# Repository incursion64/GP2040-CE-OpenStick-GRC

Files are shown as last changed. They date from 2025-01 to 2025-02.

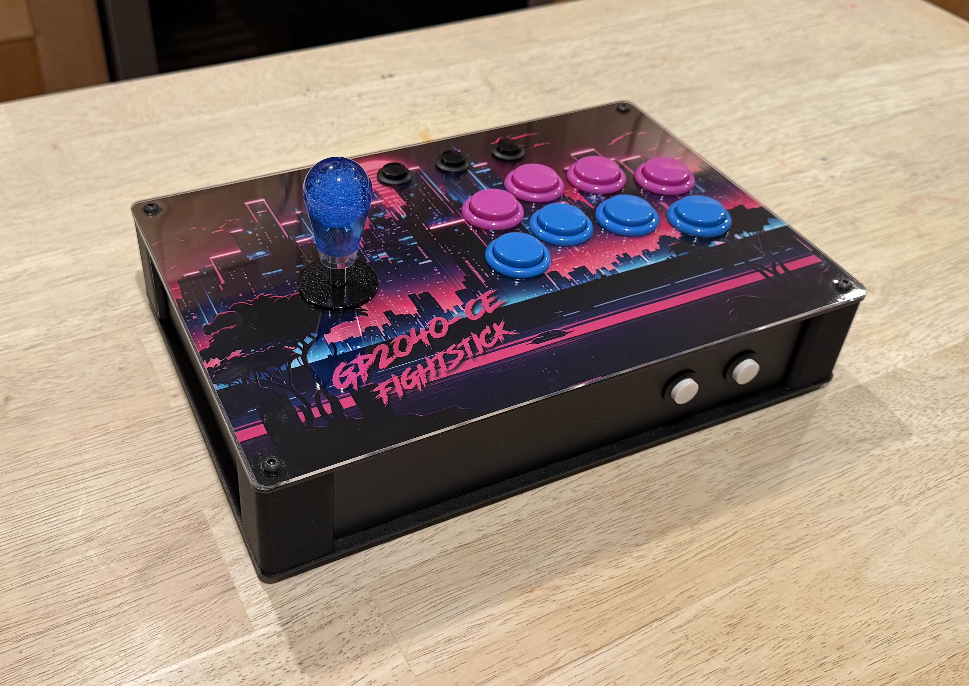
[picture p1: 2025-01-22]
z_readme assets/IMG_3226.jpg

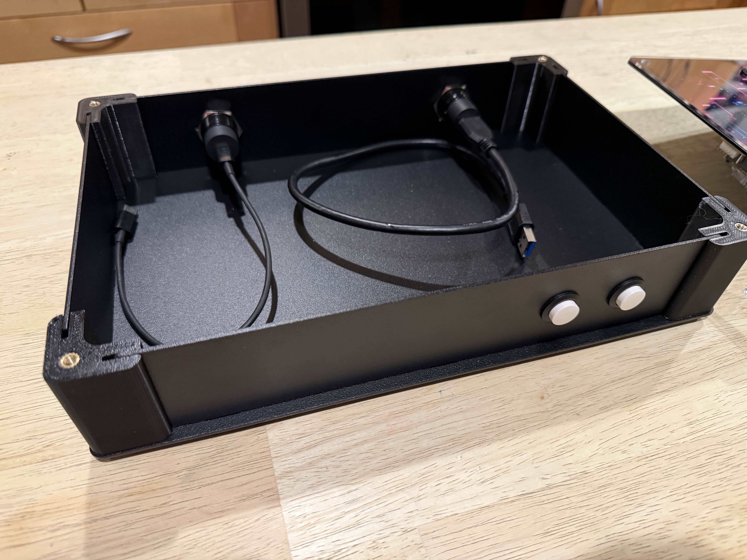
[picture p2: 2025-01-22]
z_readme assets/IMG_3221.jpg

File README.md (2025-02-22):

# GP2040-CE OpenStick by Game Room Customs (gameroomcustoms.com) 
 Custom Arcade Fight Stick

 The goal here was to design something heavyweight and durable but also offer something that was modular and easy to build and looks nice. 
 Steel Construction - 14GA CRS - Powder Coated
 3D Printed PETG Corners with threaded M4 Inserts
 3D Printed Custom Stick Spacer (to control height of the stick petruding from the case toper) This height is really based on preference. 
 Custom printed & machine cut graphics
 1.6mm Clear Acrylic Cover/graphic protector
 Rubber Non Slip feet







Included in this repository are all necessary files to process the material.
 - 2D DXF Files for laser cut metal & plastic cover
 - STL files for 3D printed Corners and spacer
 - PDF dimensionalized Prints
 - Bill of Materials for what i used

Graphic Template has not been included as you need only import the 2D DXF to Adobe illustrator or preferred program to process your artwork. 
If you decide to go with a snap in type button, be mindful that you can work with the approx 3-4mm thickness. I was able to get Sanwa genuine and clones in there. For the
clone types i had to make sure clips/anchors pushed out all the way so the button is secure. 1/16 or 1.6mm clear acrylic is recommended when usinf geniune sanwa buttons. 

Also note that i use a stick spacer.  This is not necessary if you want your stick to sit higher, but i added a 6mm (1/4") thick spacer to set the height where i like it. You could always add stick extensions as well. 

At a later date i will offer the build components or pre-built kits on my shop if anyone is interested.  
https://gameroomcustoms.com/

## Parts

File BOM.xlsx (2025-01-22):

BOM | Part | Description | Qty
1 | 100-100-101 - Corner Brackets | Black PETG - 3D Print | 4
2 | 100-100-102 - Stick Spacer | Black PETG - 3D Print | 1
3 | 100-100-103 - Top Plate | 14GA CRS - Laser Cut & Powder Coated Raven Black | 1
4 | 100-100-104 - Bottom Plate | 14GA CRS - Laser Cut & Powder Coated Raven Black | 1
5 | 100-100-105 - Side Plate | 14GA CRS - Laser Cut & Powder Coated Raven Black | 2
6 | 100-100-106 - Front Plate | 14GA CRS - Laser Cut & Powder Coated Raven Black | 1
7 | 100-100-107 - Back Plate Dual | 14GA CRS - Laser Cut & Powder Coated Raven Black | 1
8 | 100-100-108 - Black Plate Single | 14GA CRS - Laser Cut & Powder Coated Raven Black | 1 | optional in lieu of dual plate
9 | 100-100-109 - Acrylic Cover | 2mm Acrylic Cover - Laser Cut | 1 | 1mm may be prefeable depending on buttons/media (such as graphic)
10 | Litoexpe M4 Threaded Inserts | Brass Heat Set Insert Kit knurled Insert Nuts for Plastic 3D Printing | 8
11 | LifCratms Rubber Bumpers | Transparent Rubber Cutting Board Feet, Round Clear Rubber Bumpers Feet Pads Non-Slip Bumpers | 4
12 | Flat Head Cap Screws | iexcell M5 X 16mm Flat Head Cap Screws - Black Oxide | 4
13 | 18-8 Hex Nuts | 18-8 Stainless Steel Hex Nut, Black Oxide Finish, DIN 934, Metric, M5-0.8 Thread Size, 8 mm Width Across Flats, 4 mm Thick | 4
14 | M3 Flat Hed Machine Screws | M3 X 16mm PH Flat Head Screws - Black Oxide | 4
15 | M3 Hex Nuts | M3 Hex Nuts - Black Oxide | 4
16 | M3 Nylon Spacers | 3*3*7 MM Round Spacer Nylon - Black | 4
17 | USBC Port | AVSSZ Connectors USB 3.0 2.0 Type C Metal Data Adapter C / Round Computer Data Module, Single/Dual Interface Mounting Size 22mm | 1
18 | USBA Port | AVSSZ Connectors USB 3.0 2.0 Type A Metal Data Adapter A / Round Computer Data Module, Single/Dual Interface Mounting Size 22mm | 1
19 | GP2040-CE | Advanced Breakout Board V5.6E | 1
20 | 16mm Momentary Push Button | Multiple Color Available. Amazon has a multicolor pack | 6
21 | Sanwa - OBSF-30 | Snap in 30mm Arcade Buttons | 8
22 | Sanwa - JLF-TP-8YT | JLF-TP-8YT Joystick Black Original - for Arcade Jamma Game 4 & 8 Way Adjustable | 1
23 | Harness | Fighting Board Cable 20-Pin Quick Connect | 1 | Optional
24 | USB C to USB C Wire | Short 30cm Type C to USB C Cable Fast Charging For Iphone15 Xiaomi Samsung Huawei Power BanK 25cm USB To Type C/USB C Data Cable | 1
25 | USB A to USB A | USB Male to Male Cable USB A to USB Cord USB 3.0 Cable Double End USB Cord 5Gbps for Radiator Hard Disk USB 3.0 Extender Cable. .5m Long | 1

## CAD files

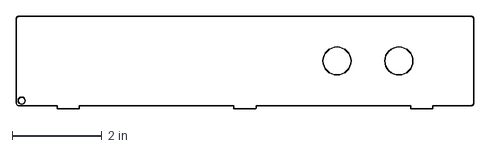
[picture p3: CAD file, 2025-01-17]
2D CAD Files/Front Plate_14GA CRS.dxf
10.2 x 2.07 in

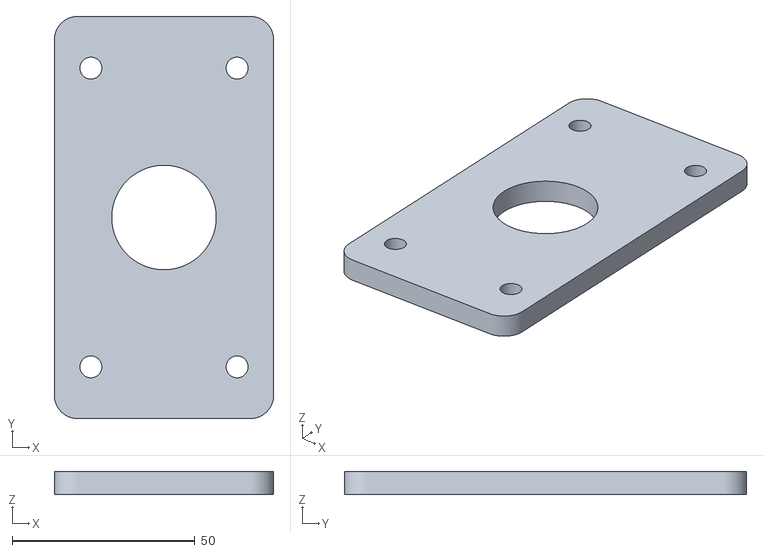
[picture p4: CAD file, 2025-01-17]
STL Files/Stick Spacer.stl
60.0 x 110.0 x 6.35

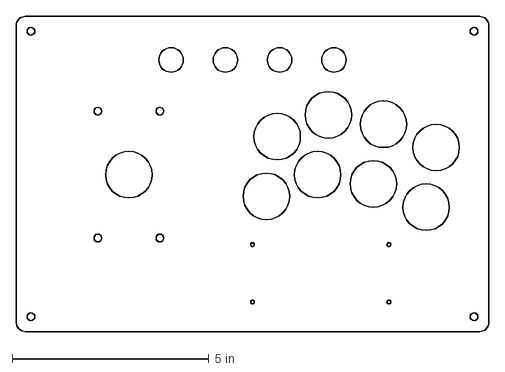
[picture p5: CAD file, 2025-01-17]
2D CAD Files/Acrylic Cover_2mm Clear.dxf
12.0 x 8.00 in

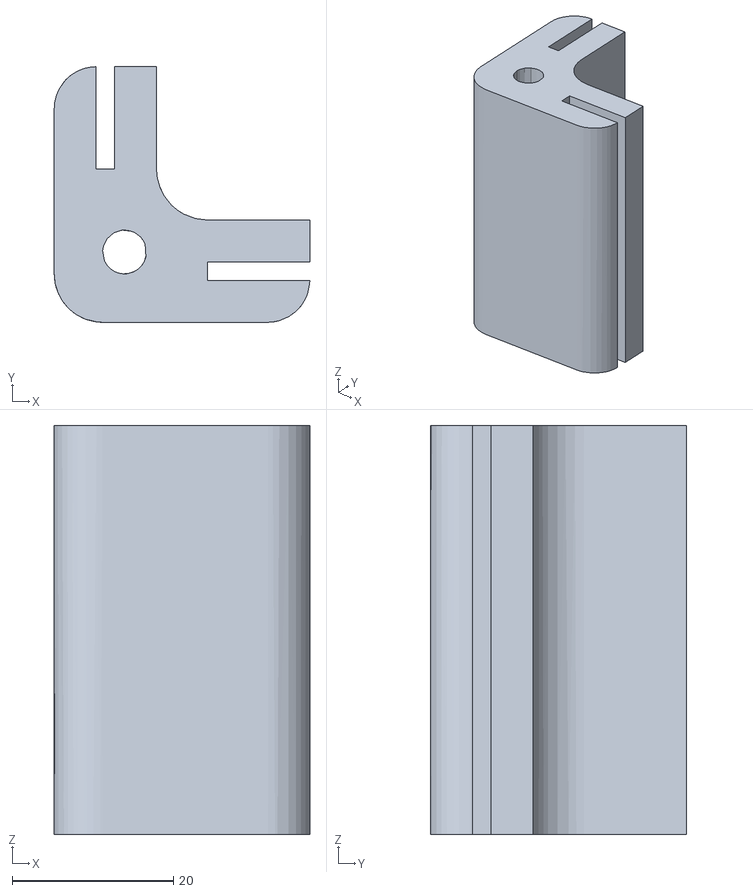
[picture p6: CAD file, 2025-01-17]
STL Files/Corner Brackets.stl
31.8 x 31.8 x 50.8

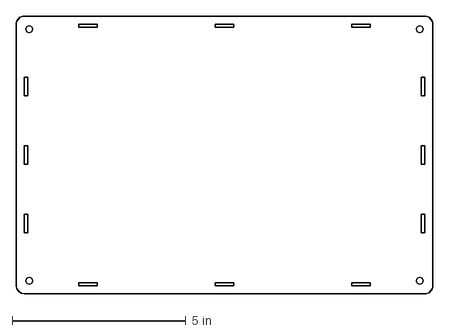
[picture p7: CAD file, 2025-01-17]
2D CAD Files/Bottom Plate_14GA.dxf
12.0 x 8.00 in

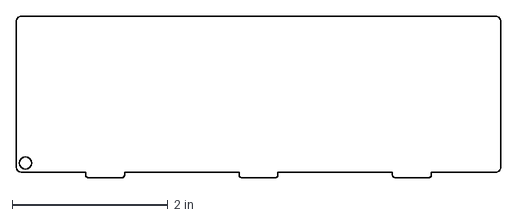
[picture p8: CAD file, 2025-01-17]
2D CAD Files/Side Plates_14GA CRS.dxf
6.22 x 2.07 in

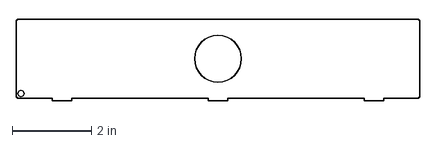
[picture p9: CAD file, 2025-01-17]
2D CAD Files/Black Plate Single Mount_14GA CRS.dxf
10.2 x 2.07 in

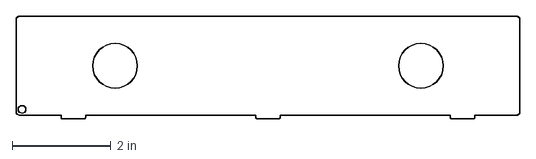
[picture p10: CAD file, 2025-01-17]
2D CAD Files/Back Plate Dual Mount_14GA CRS.dxf
10.2 x 2.07 in

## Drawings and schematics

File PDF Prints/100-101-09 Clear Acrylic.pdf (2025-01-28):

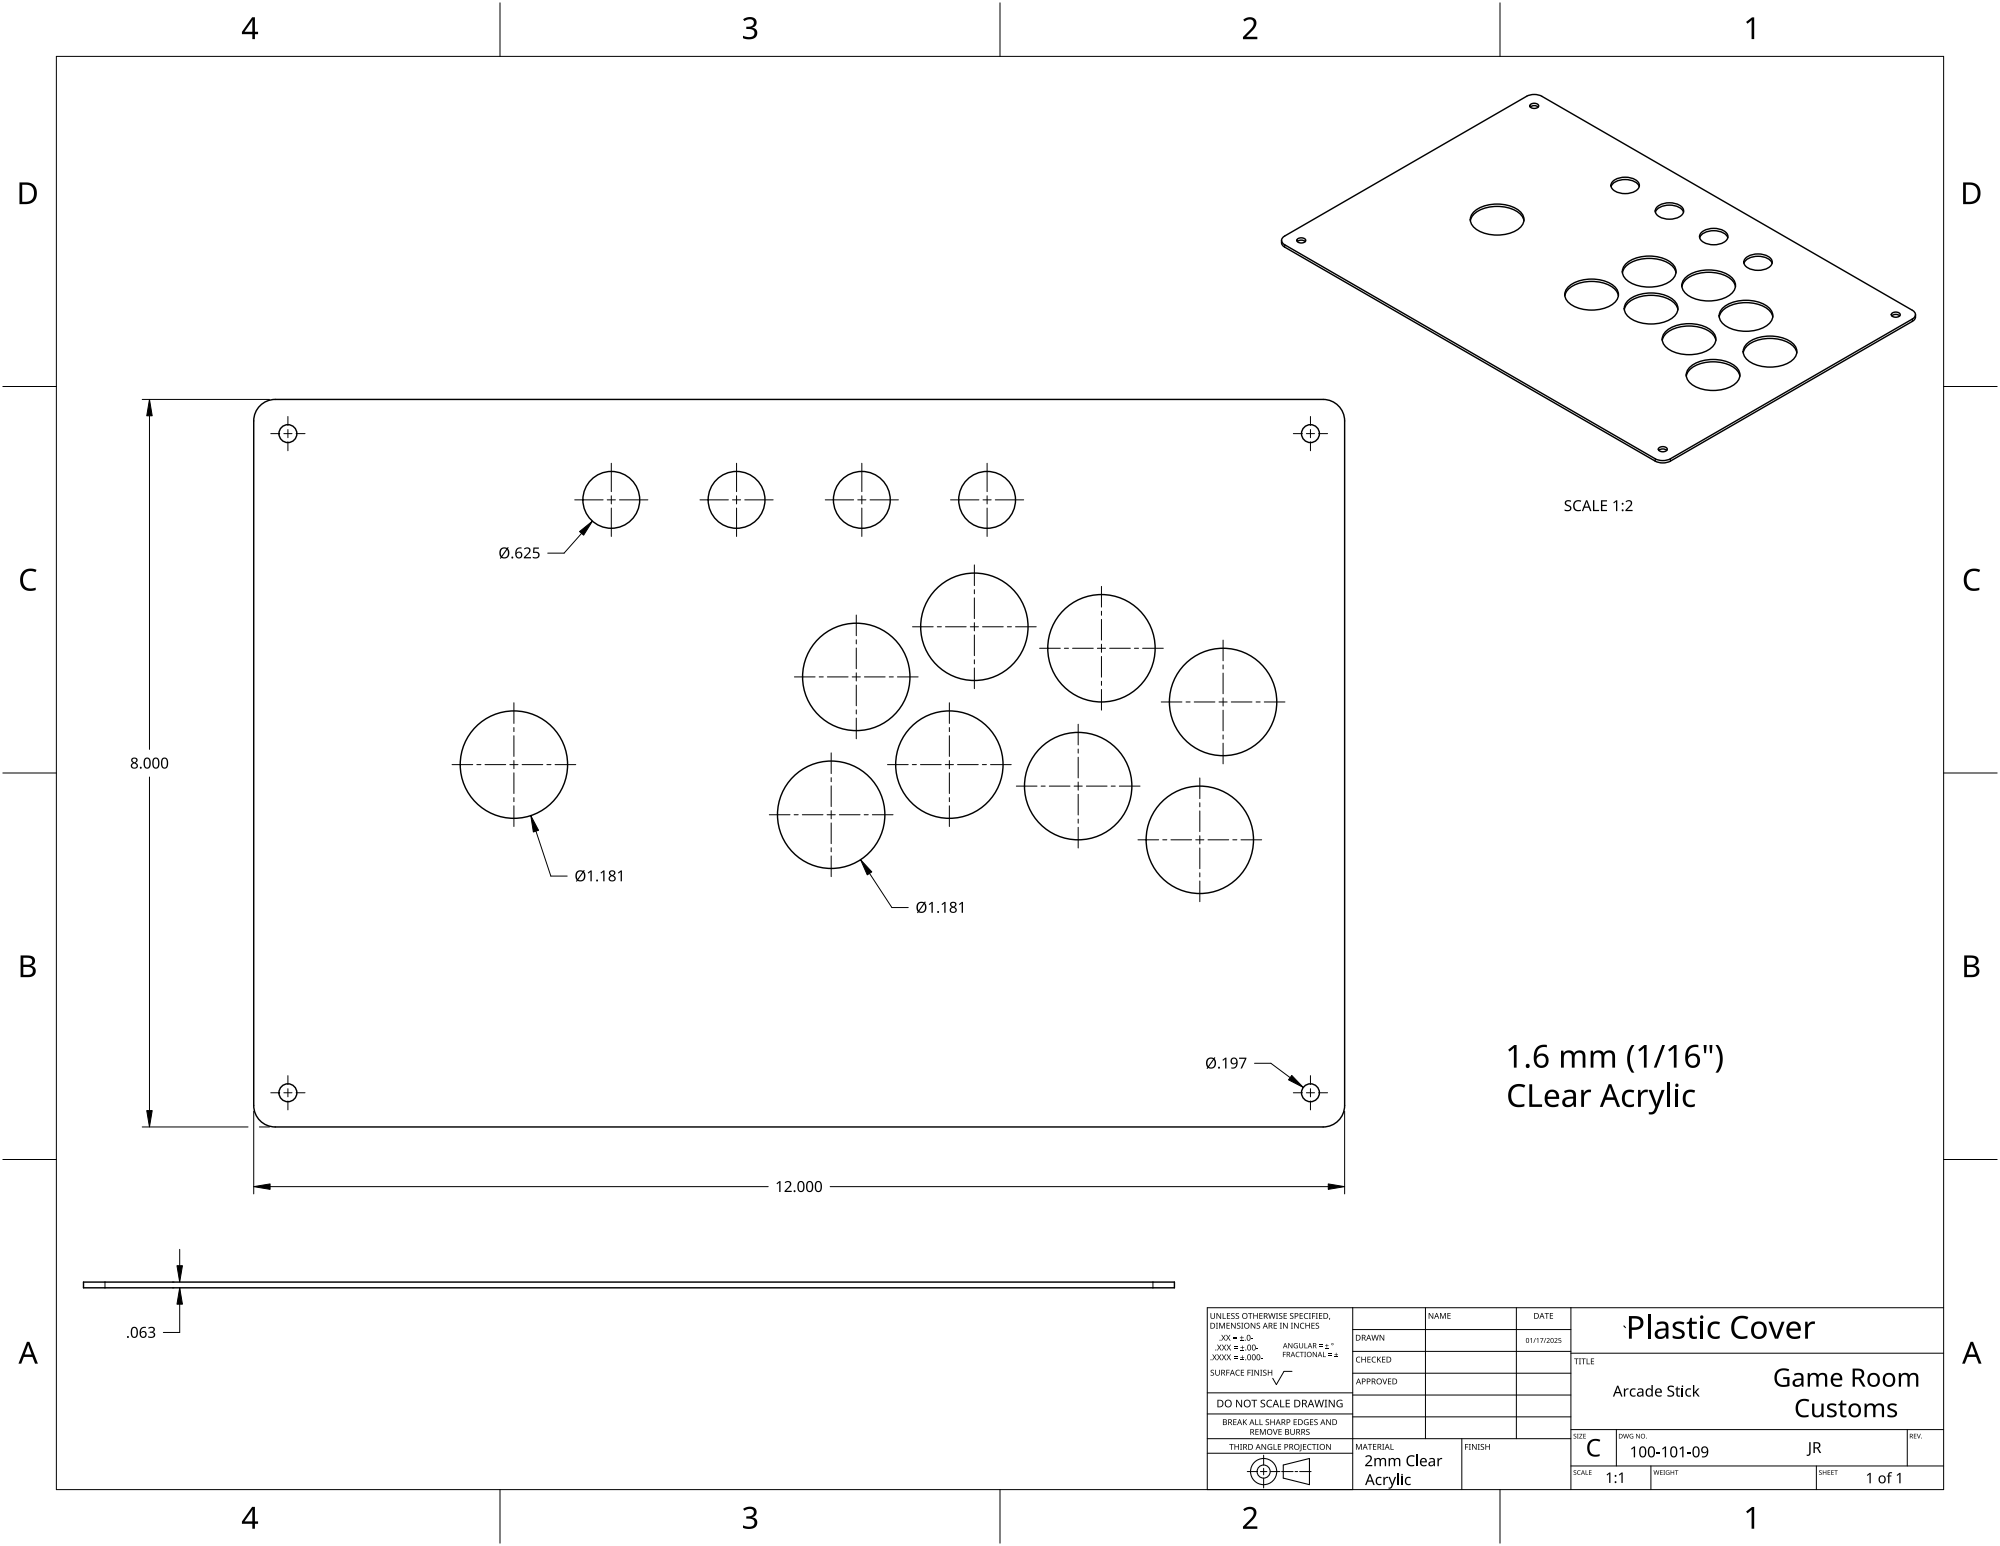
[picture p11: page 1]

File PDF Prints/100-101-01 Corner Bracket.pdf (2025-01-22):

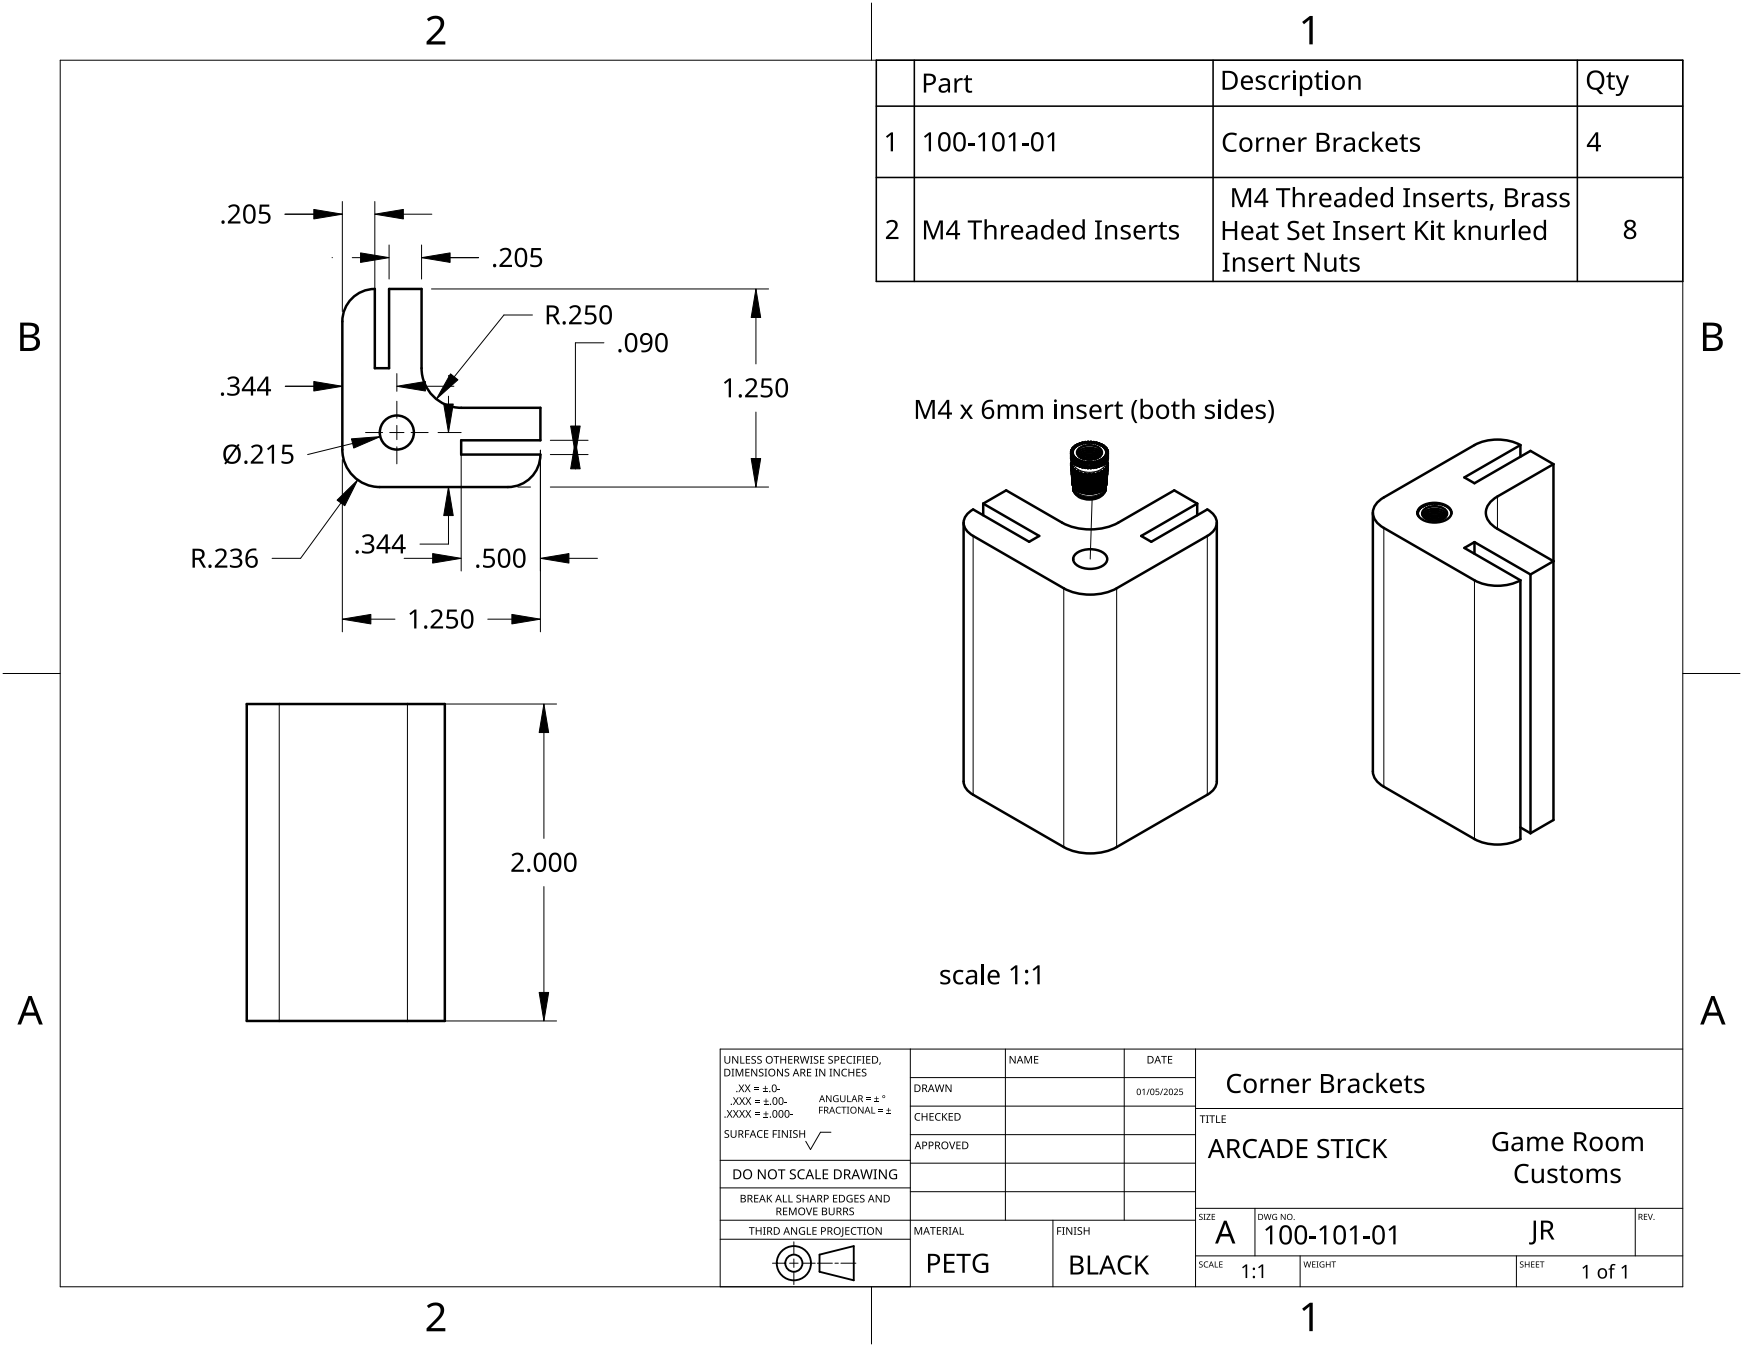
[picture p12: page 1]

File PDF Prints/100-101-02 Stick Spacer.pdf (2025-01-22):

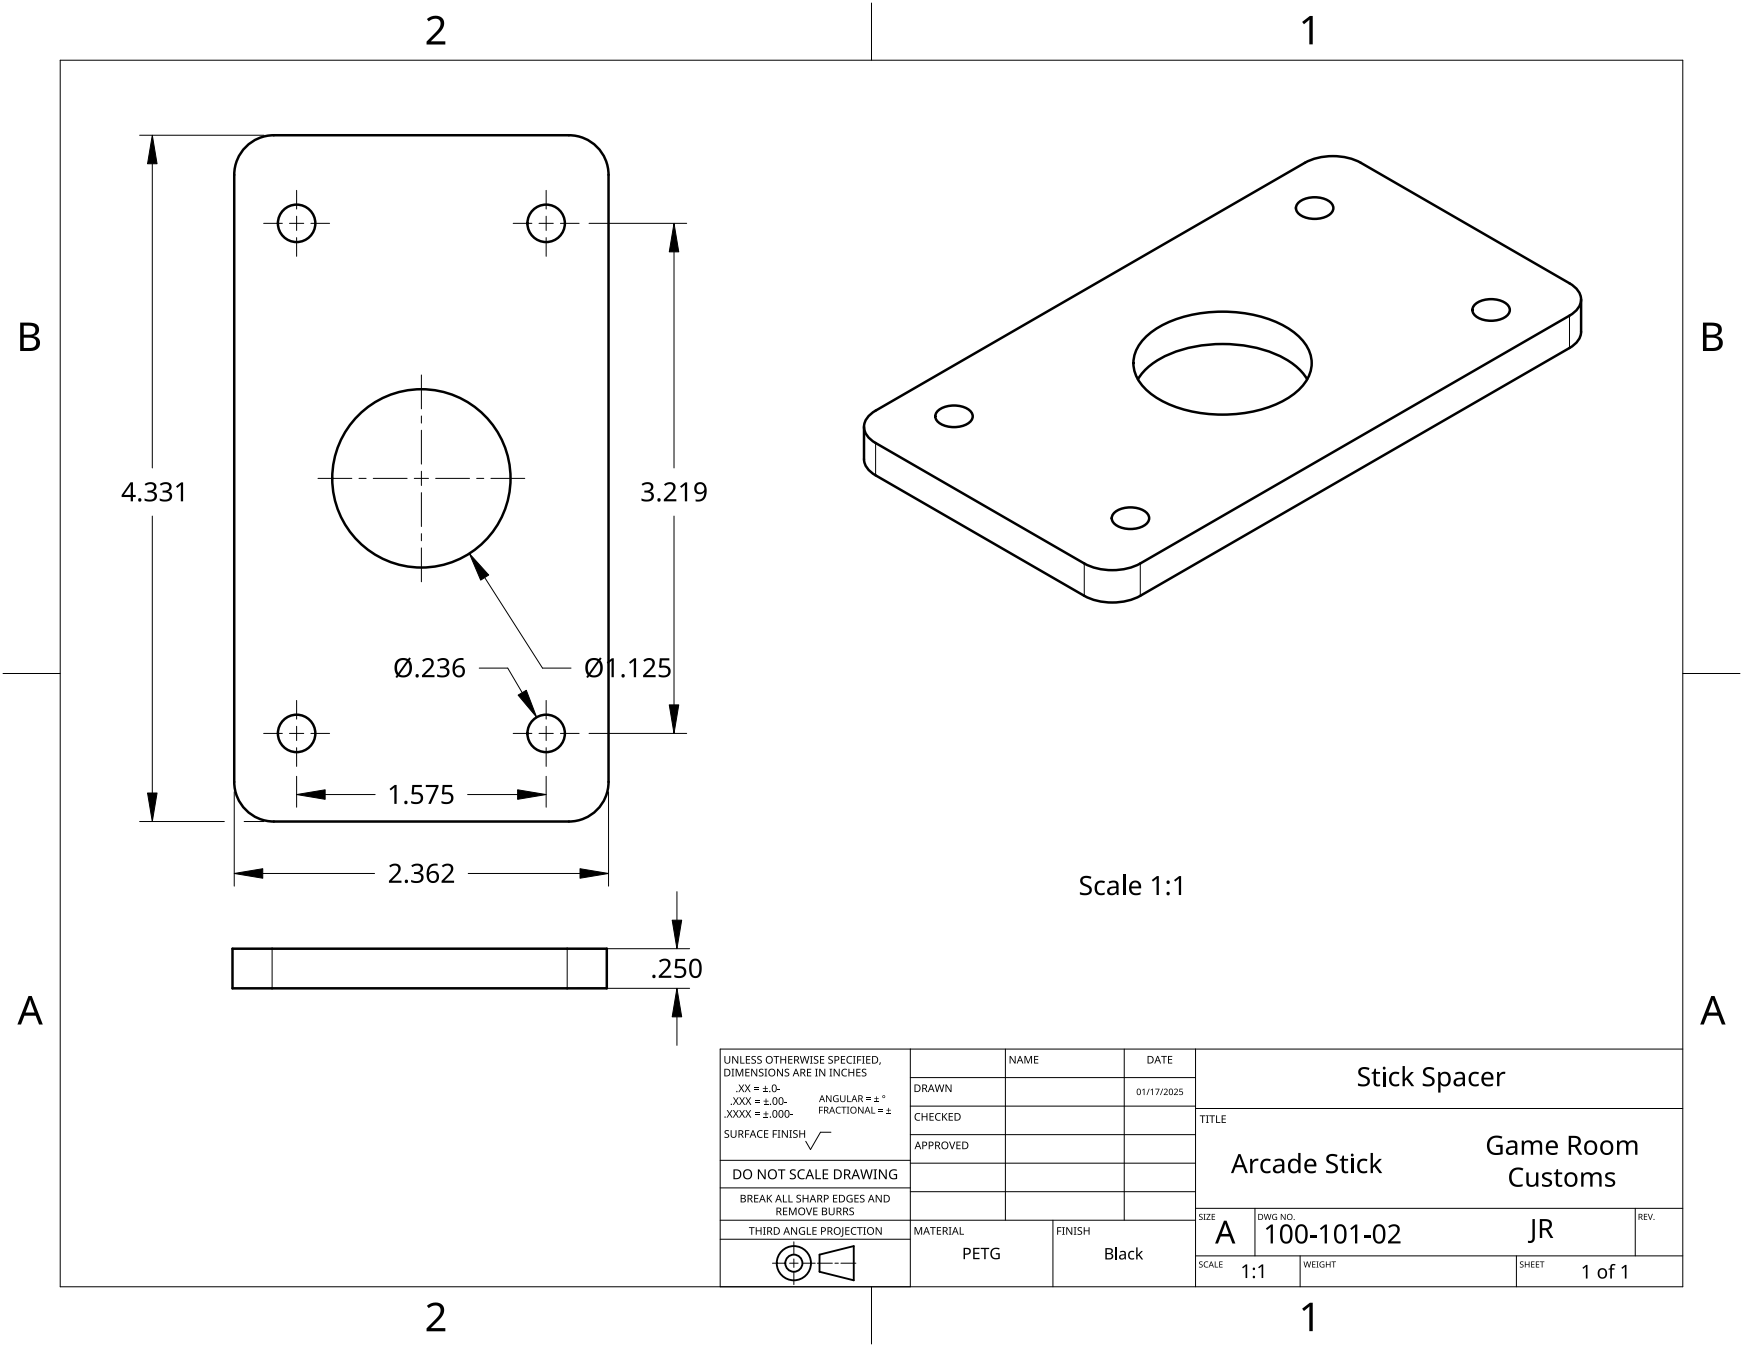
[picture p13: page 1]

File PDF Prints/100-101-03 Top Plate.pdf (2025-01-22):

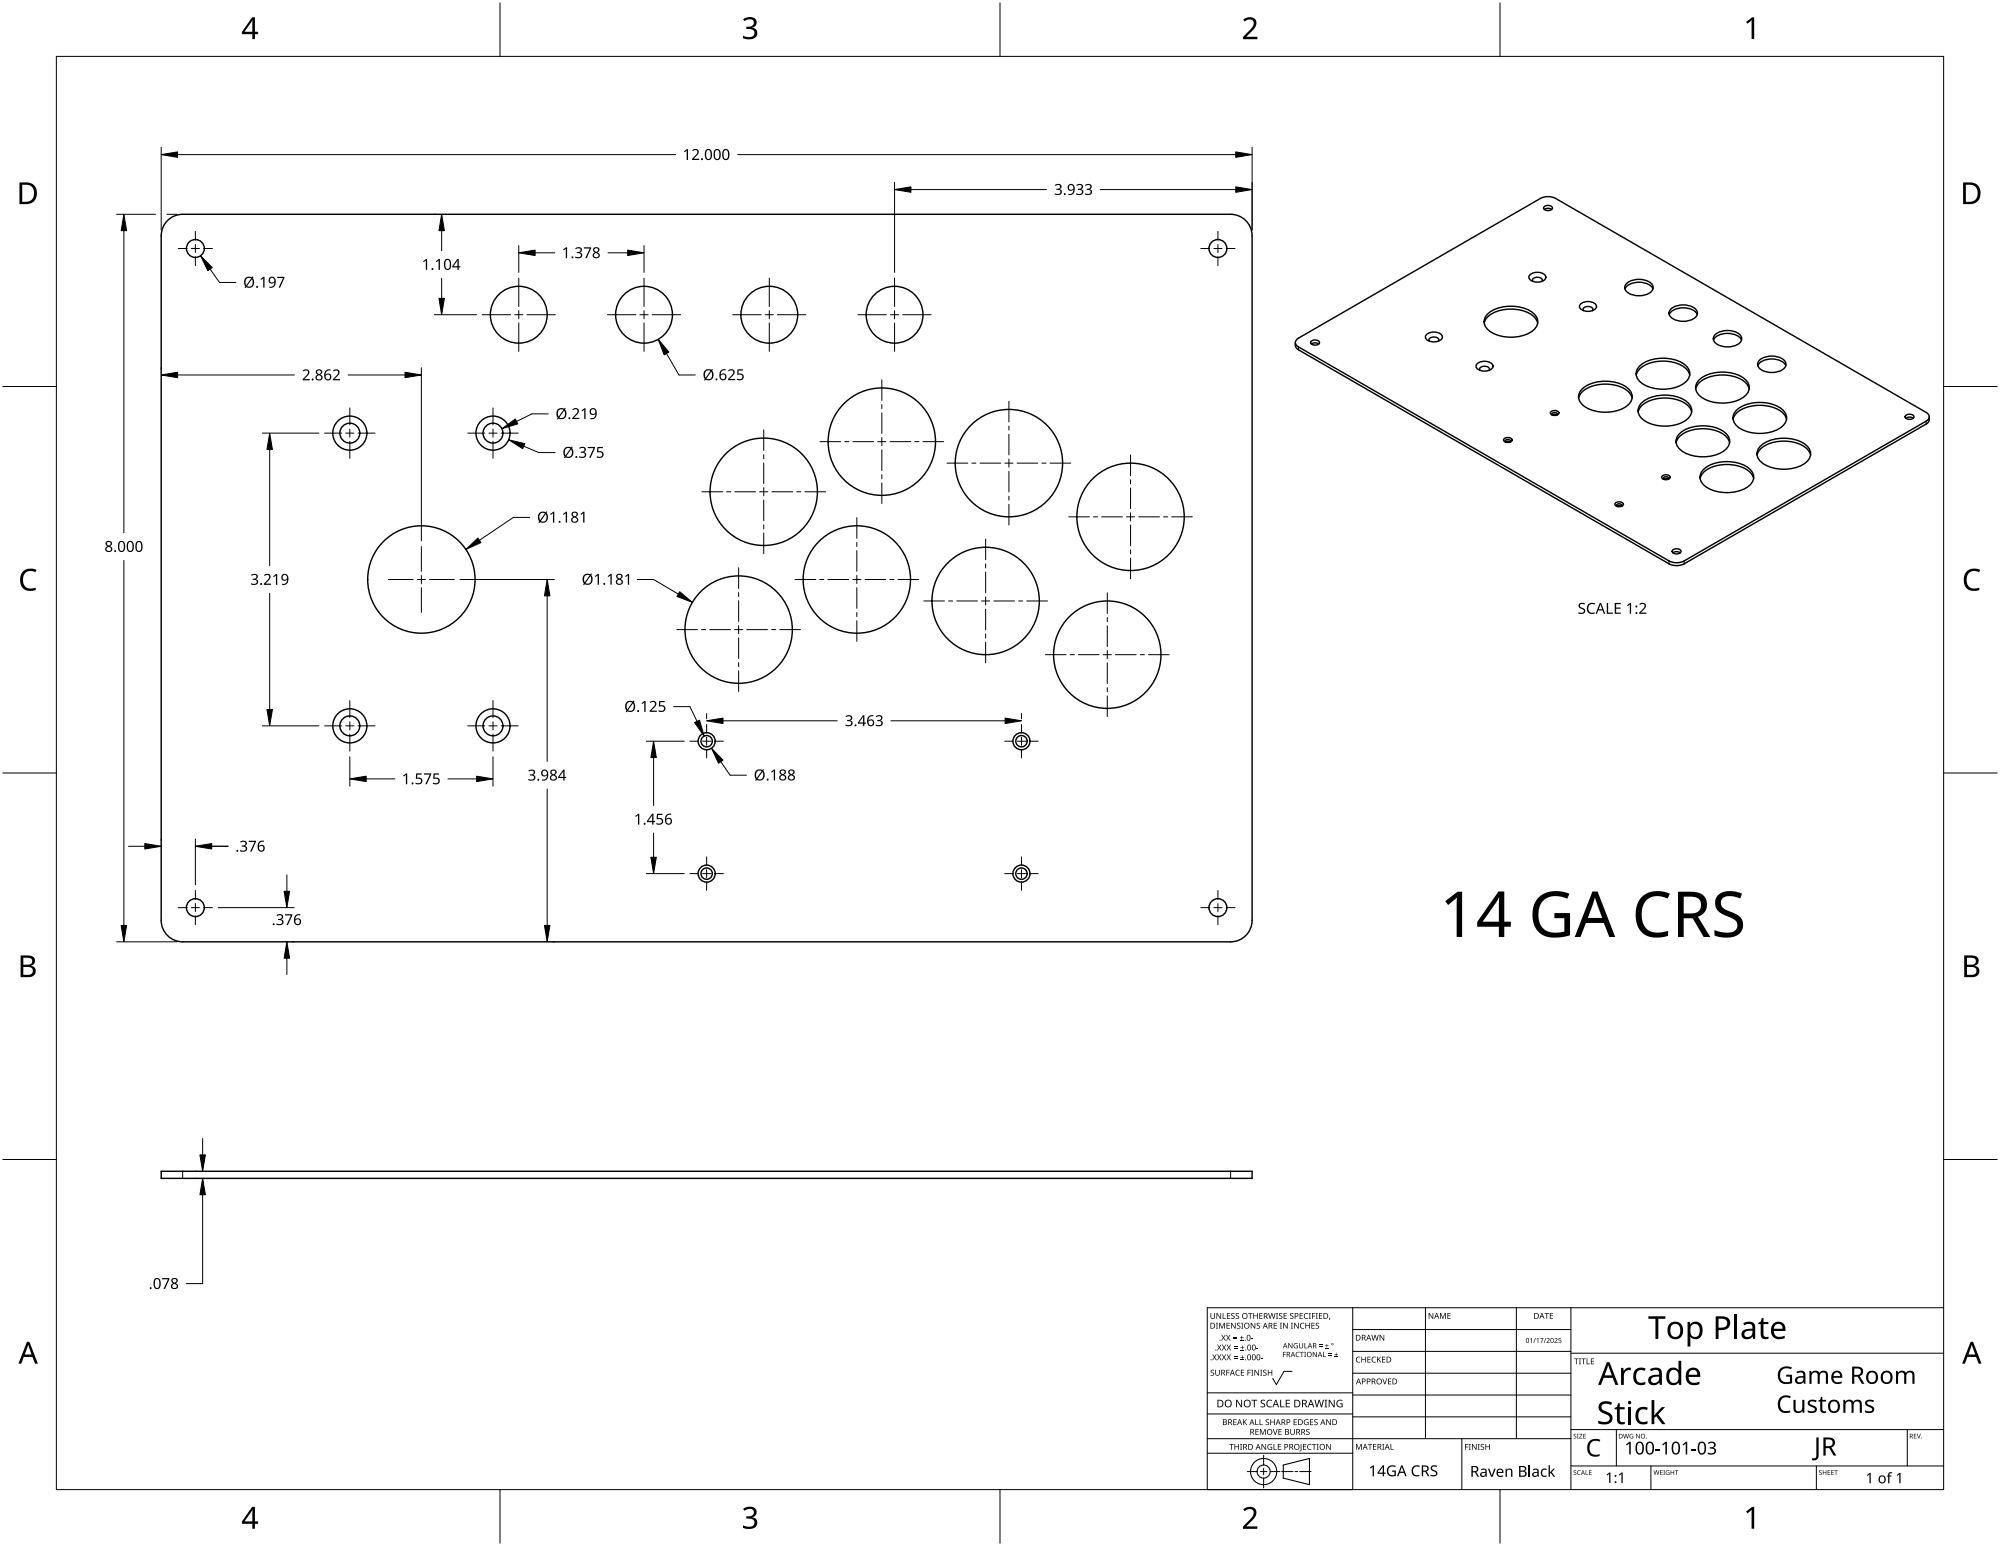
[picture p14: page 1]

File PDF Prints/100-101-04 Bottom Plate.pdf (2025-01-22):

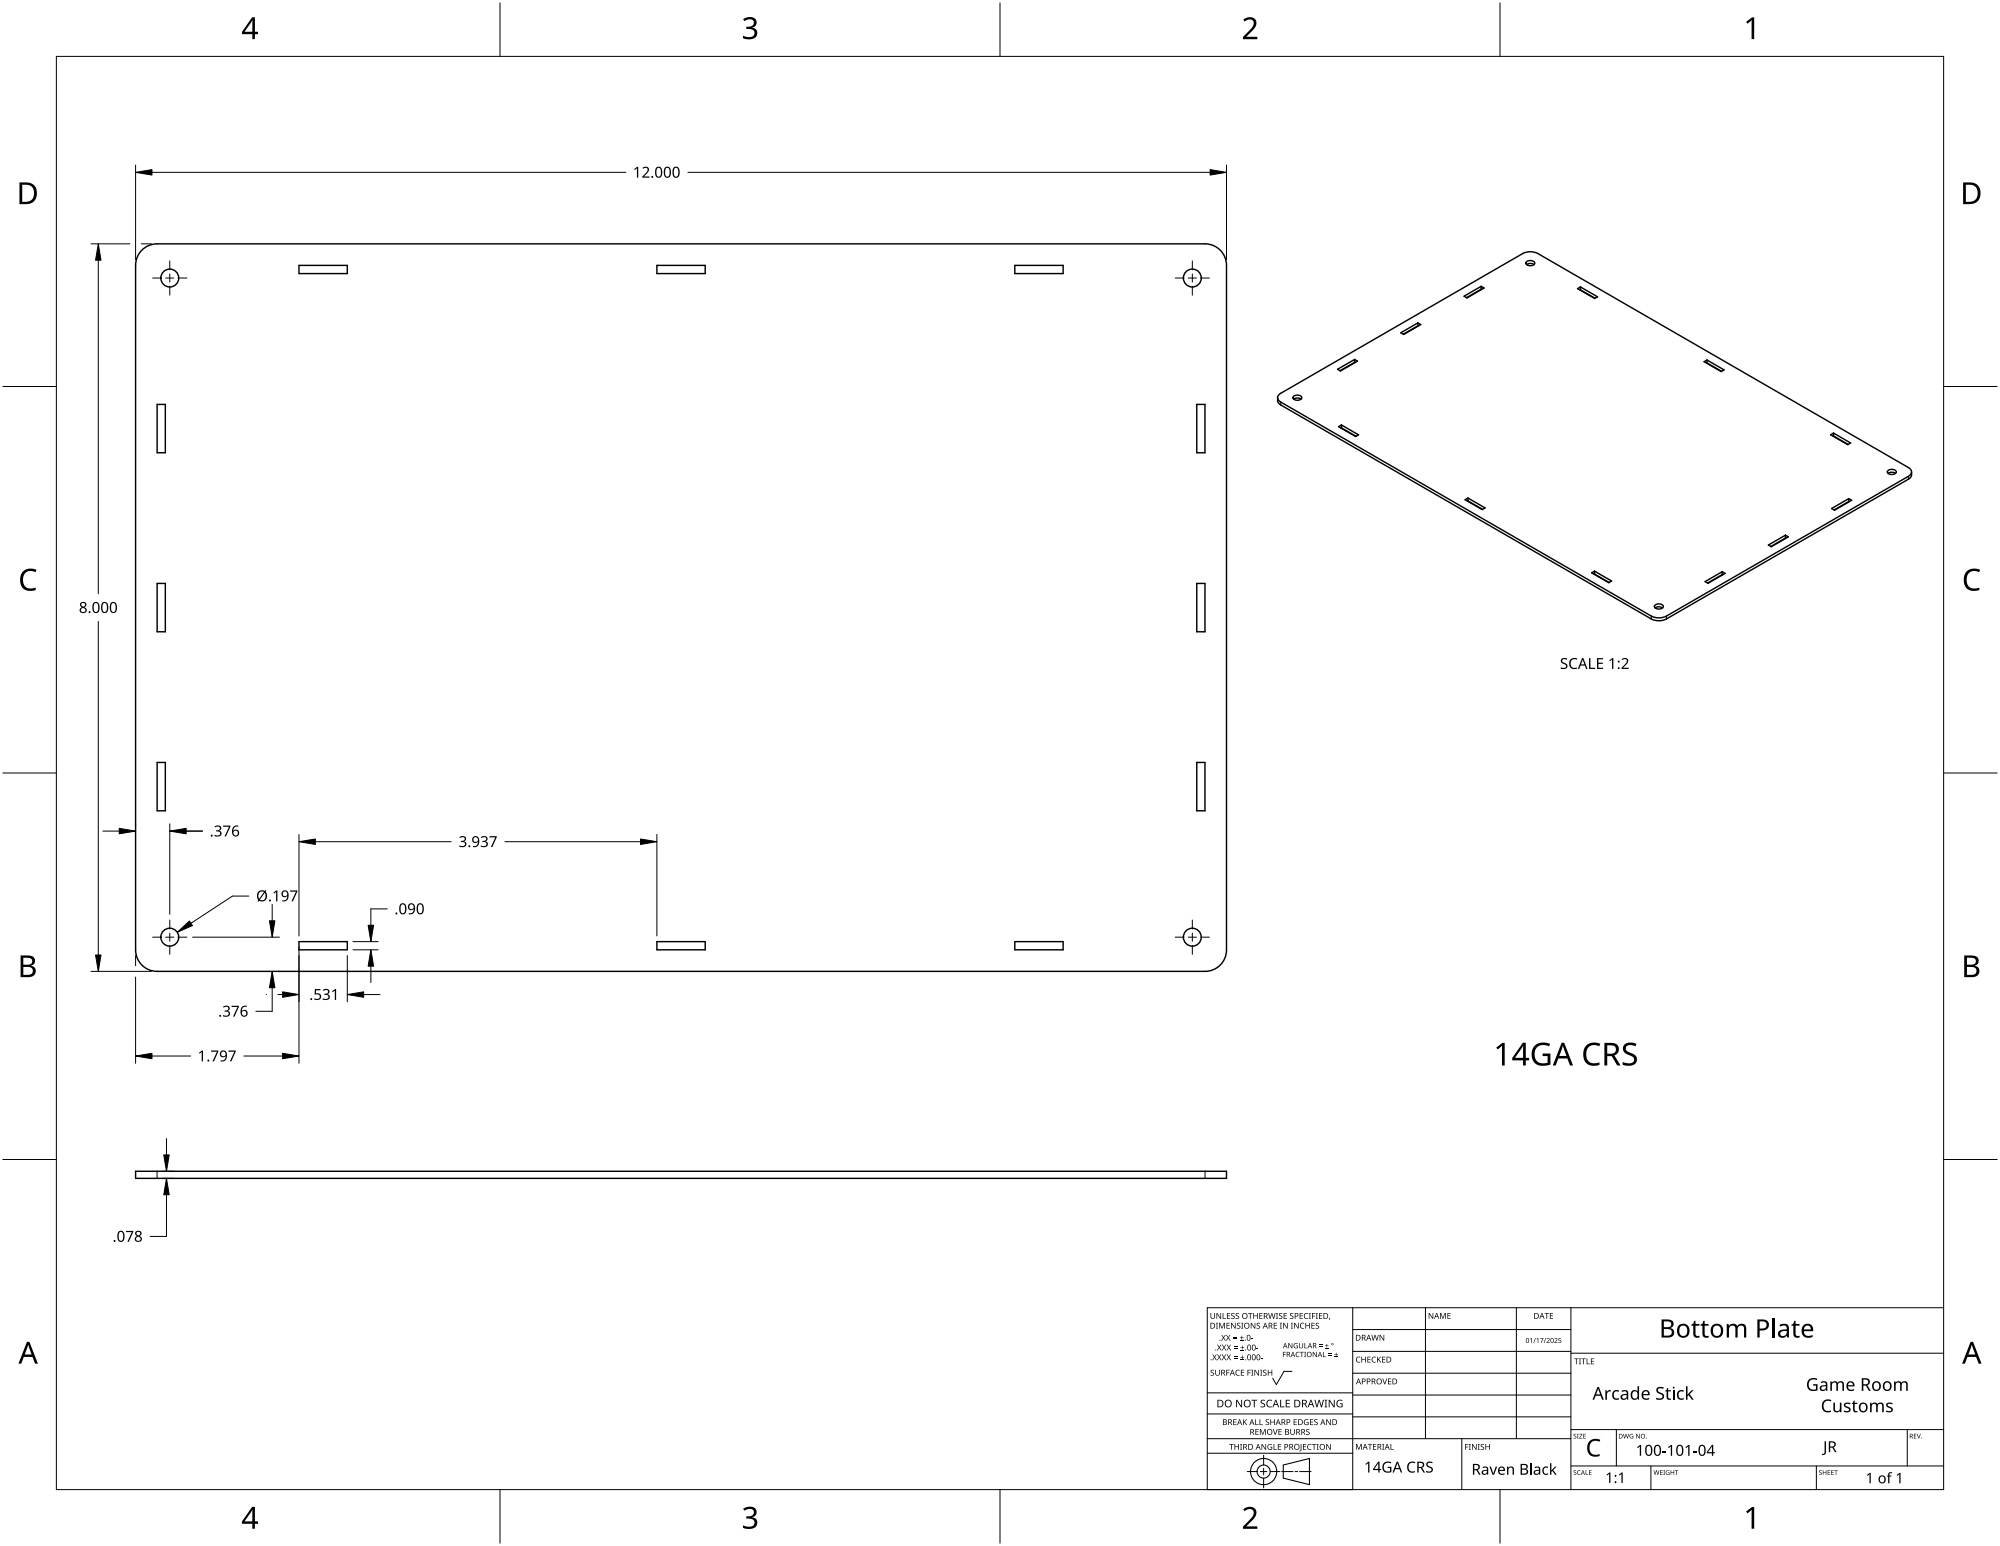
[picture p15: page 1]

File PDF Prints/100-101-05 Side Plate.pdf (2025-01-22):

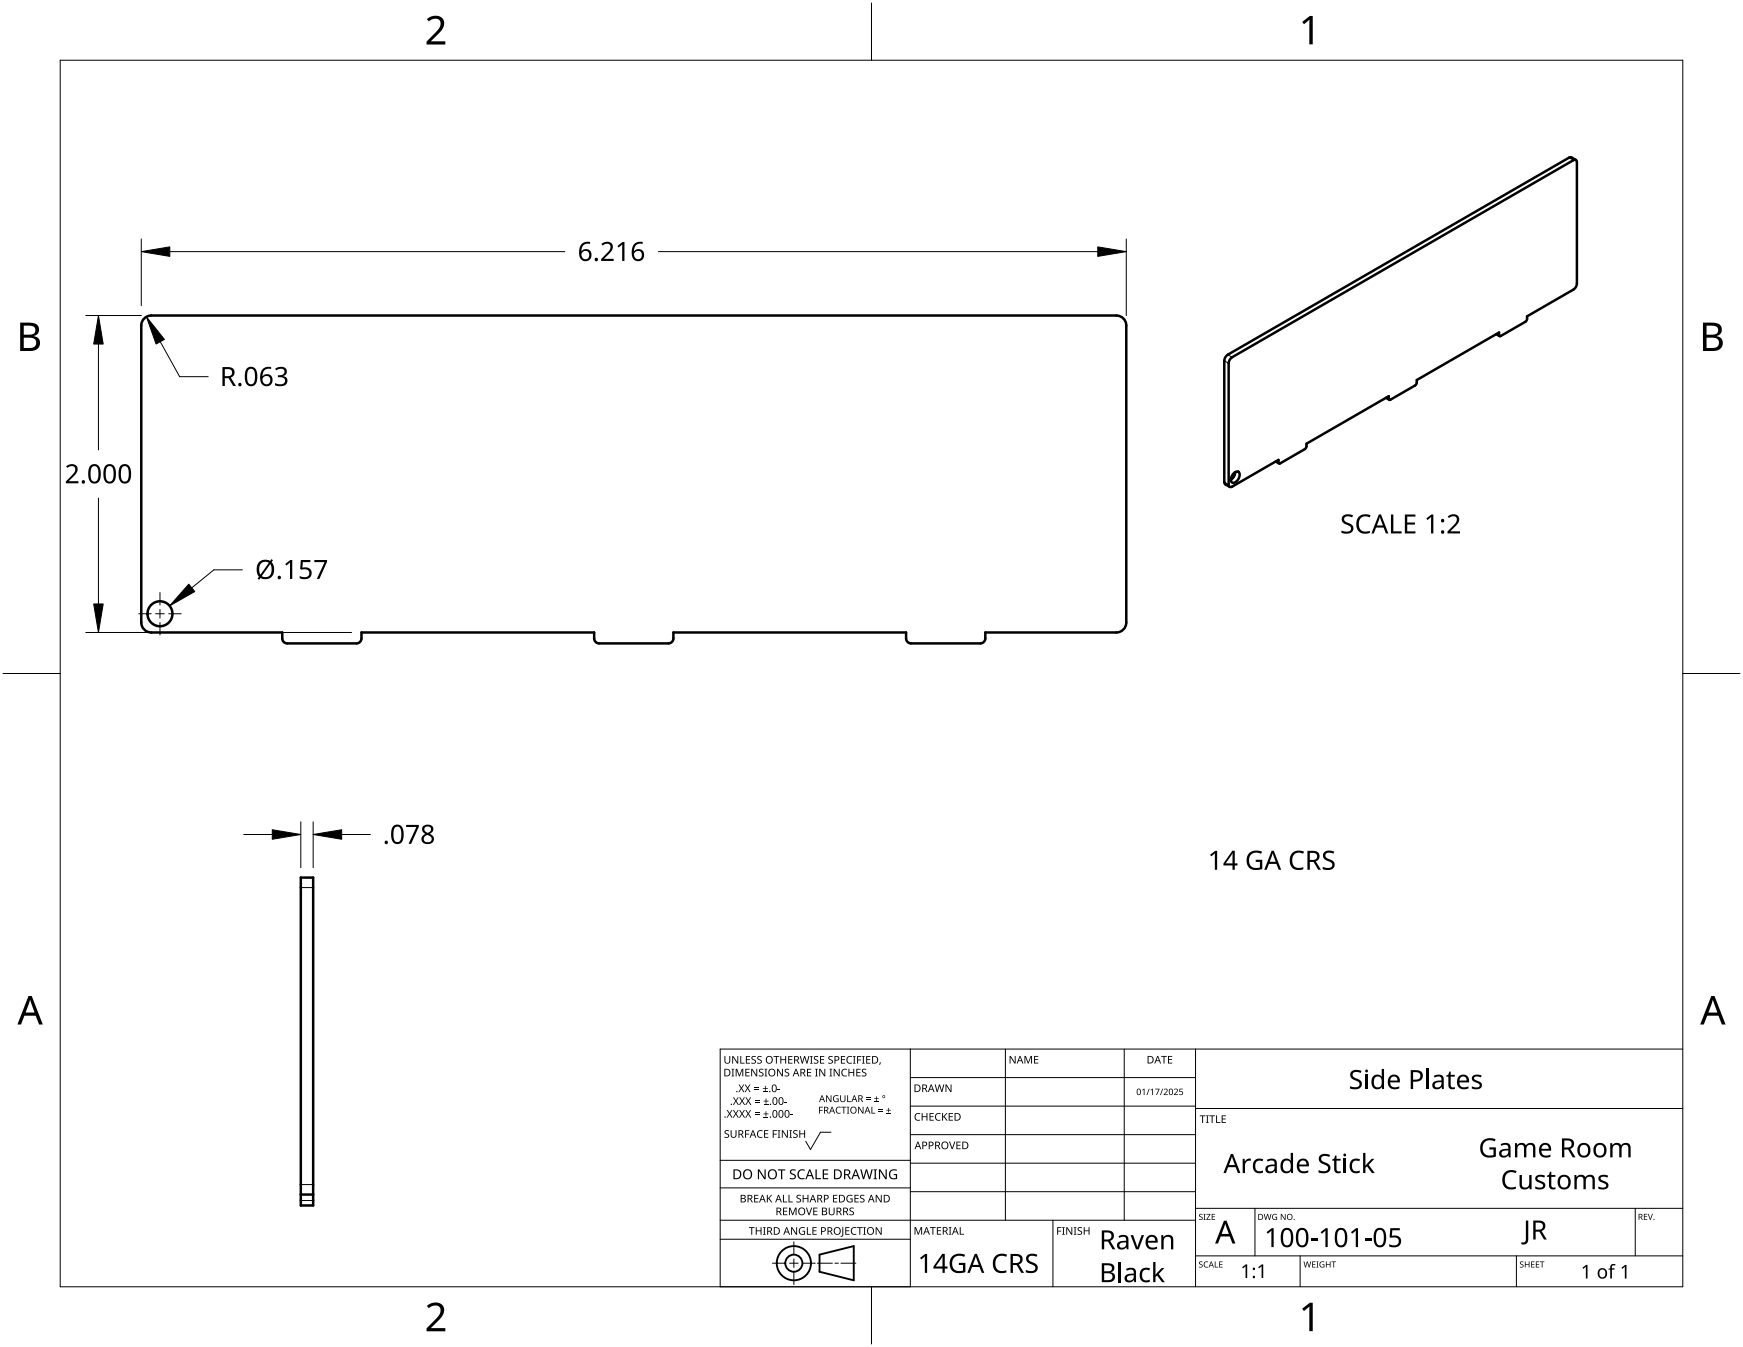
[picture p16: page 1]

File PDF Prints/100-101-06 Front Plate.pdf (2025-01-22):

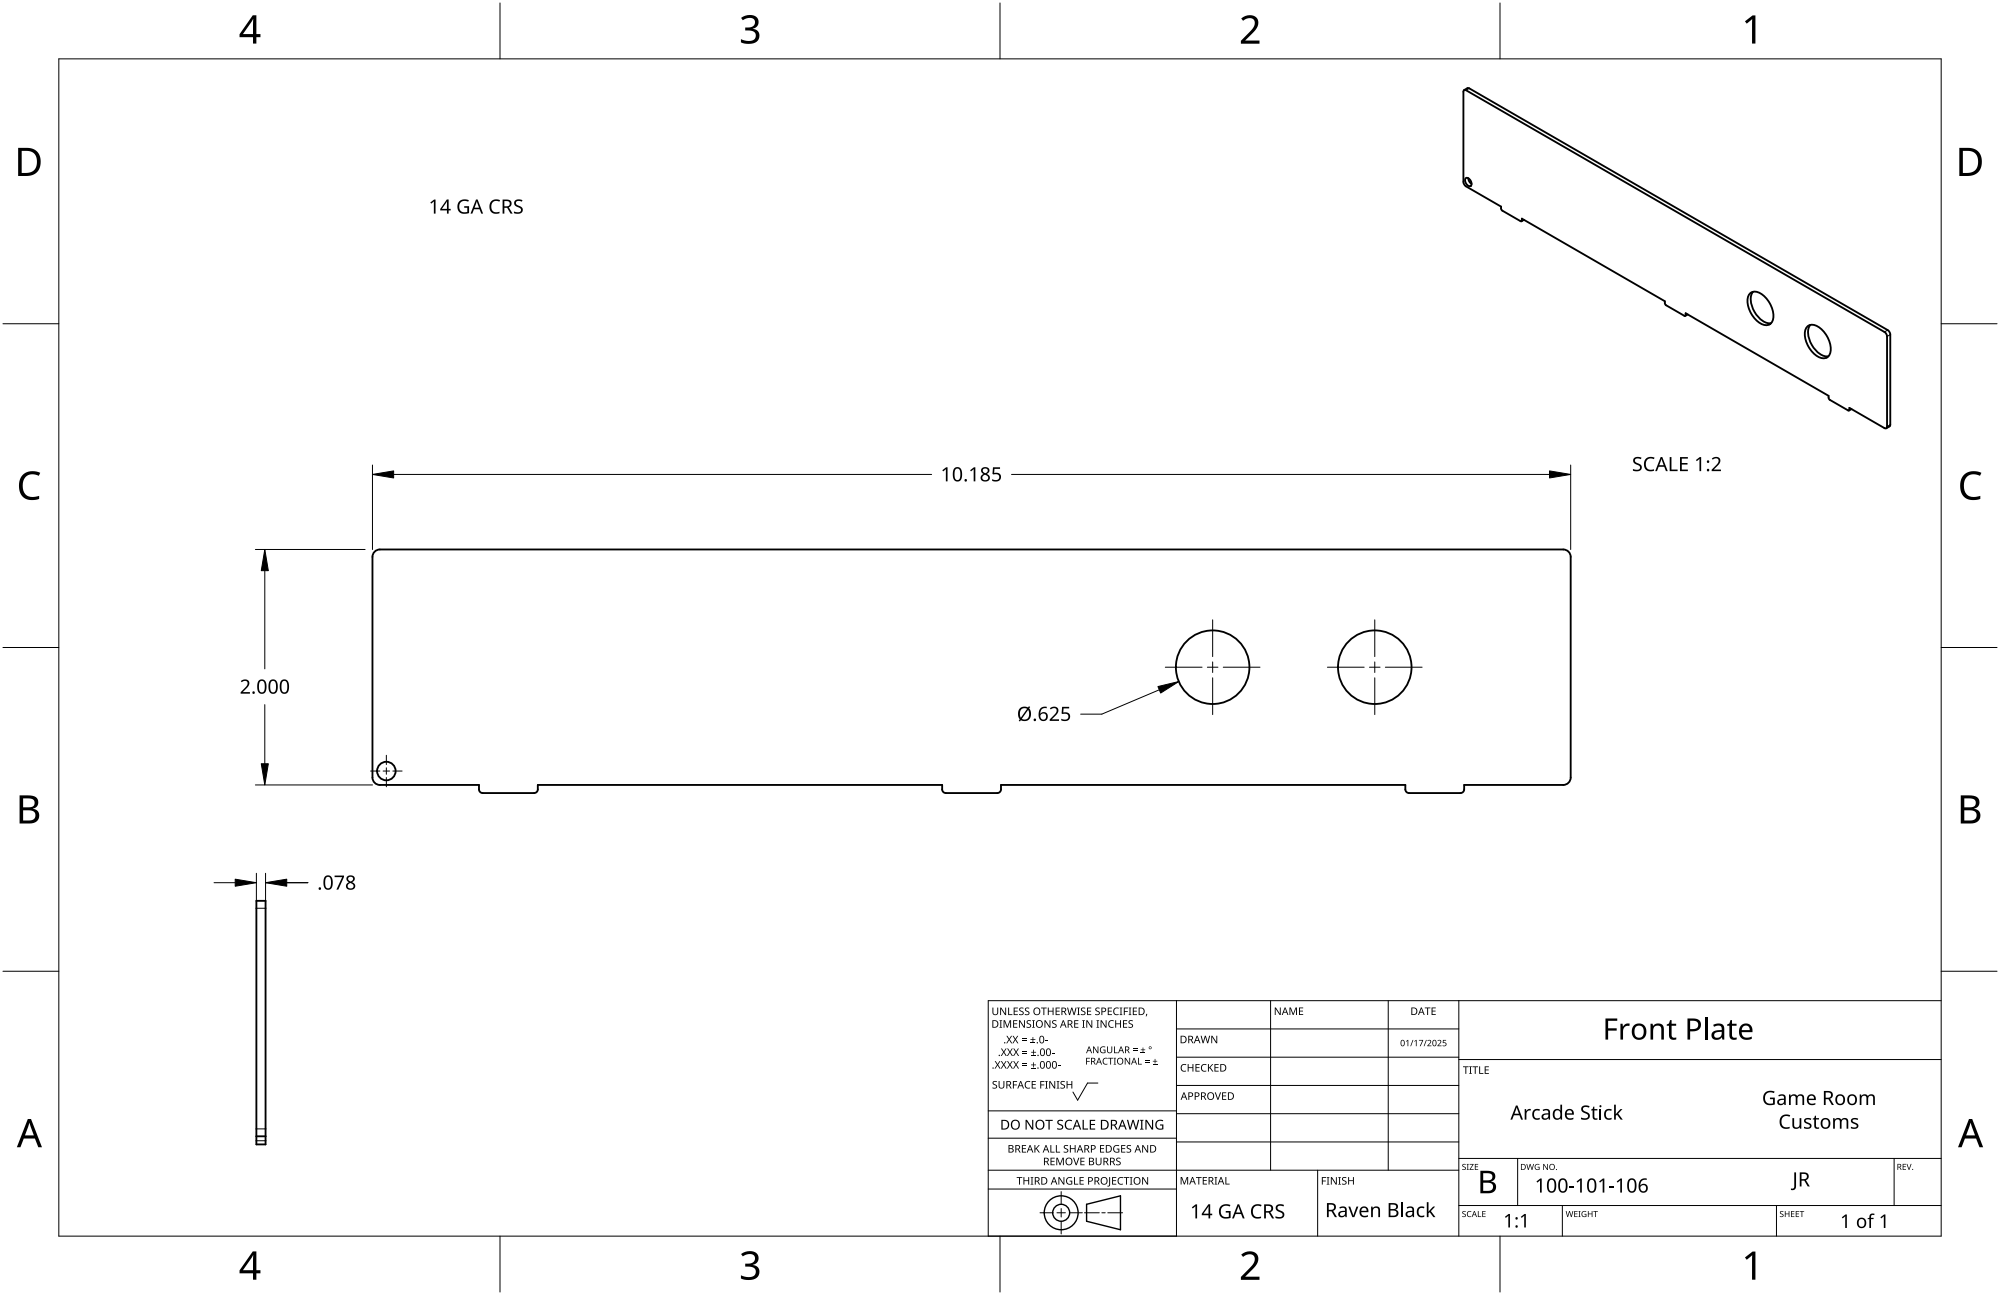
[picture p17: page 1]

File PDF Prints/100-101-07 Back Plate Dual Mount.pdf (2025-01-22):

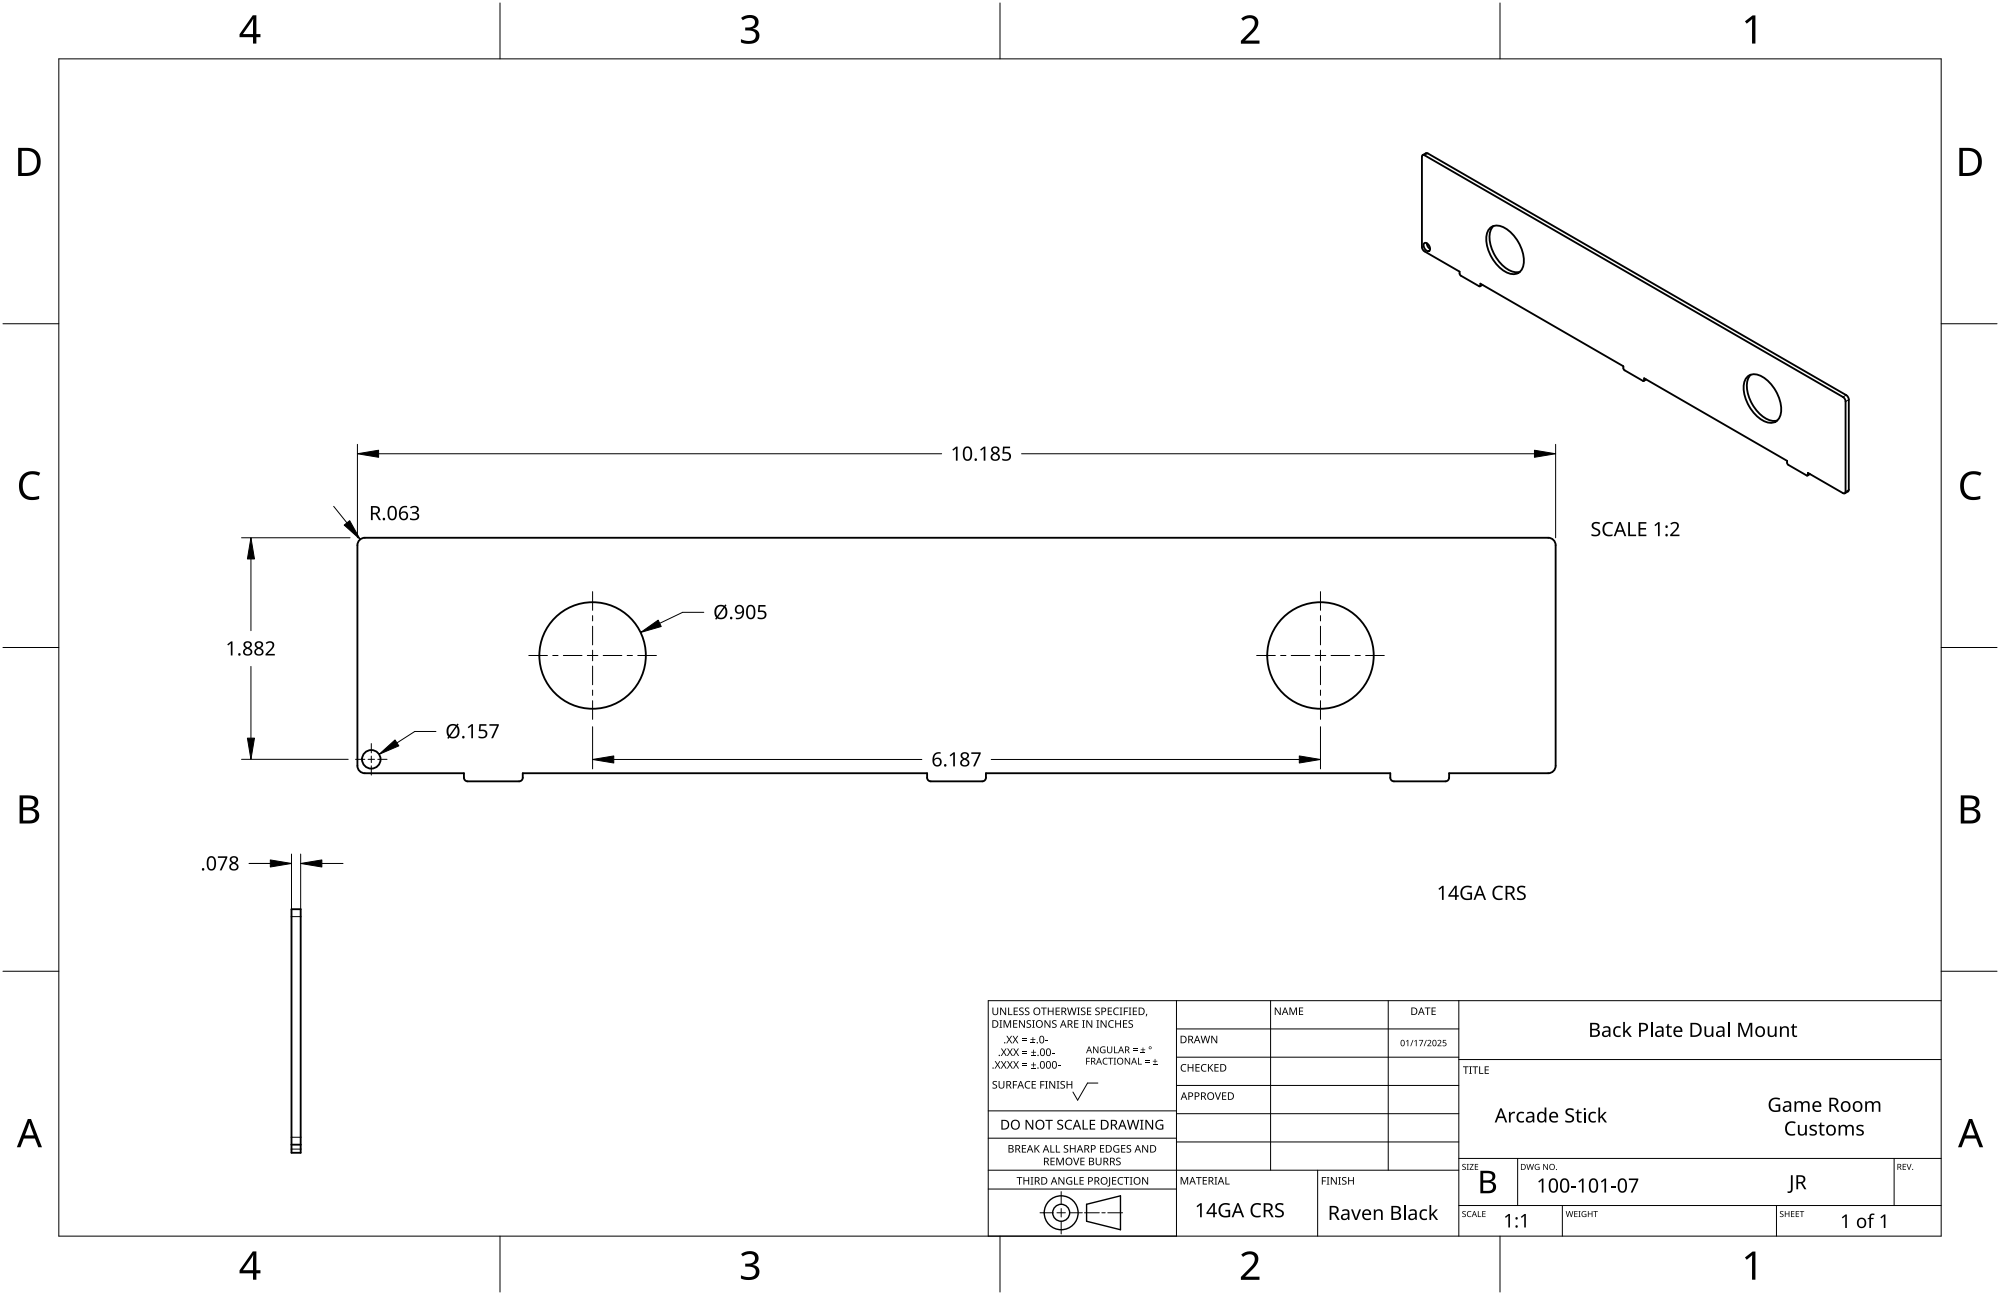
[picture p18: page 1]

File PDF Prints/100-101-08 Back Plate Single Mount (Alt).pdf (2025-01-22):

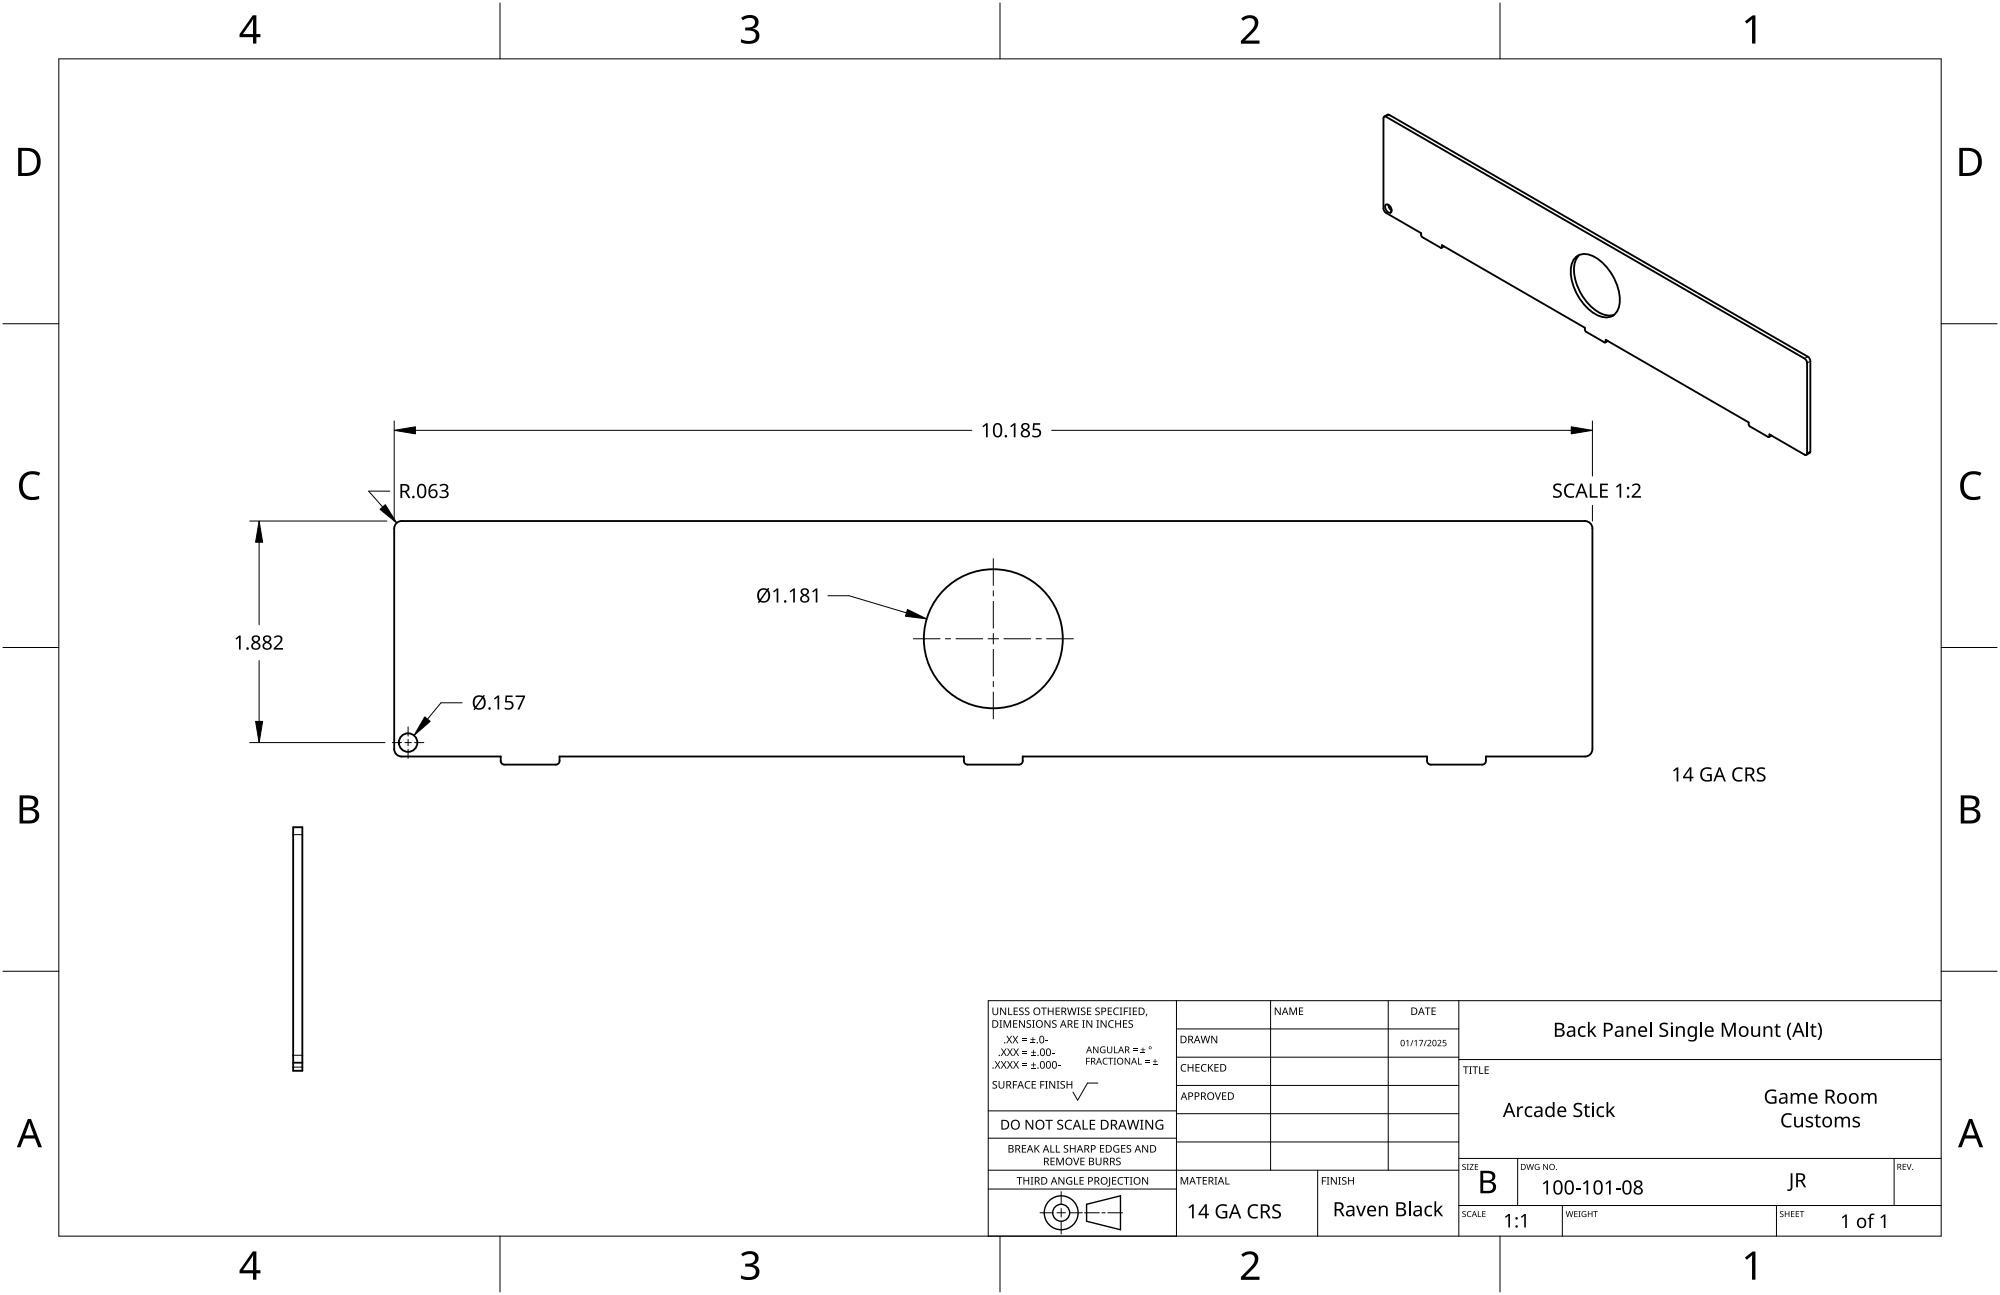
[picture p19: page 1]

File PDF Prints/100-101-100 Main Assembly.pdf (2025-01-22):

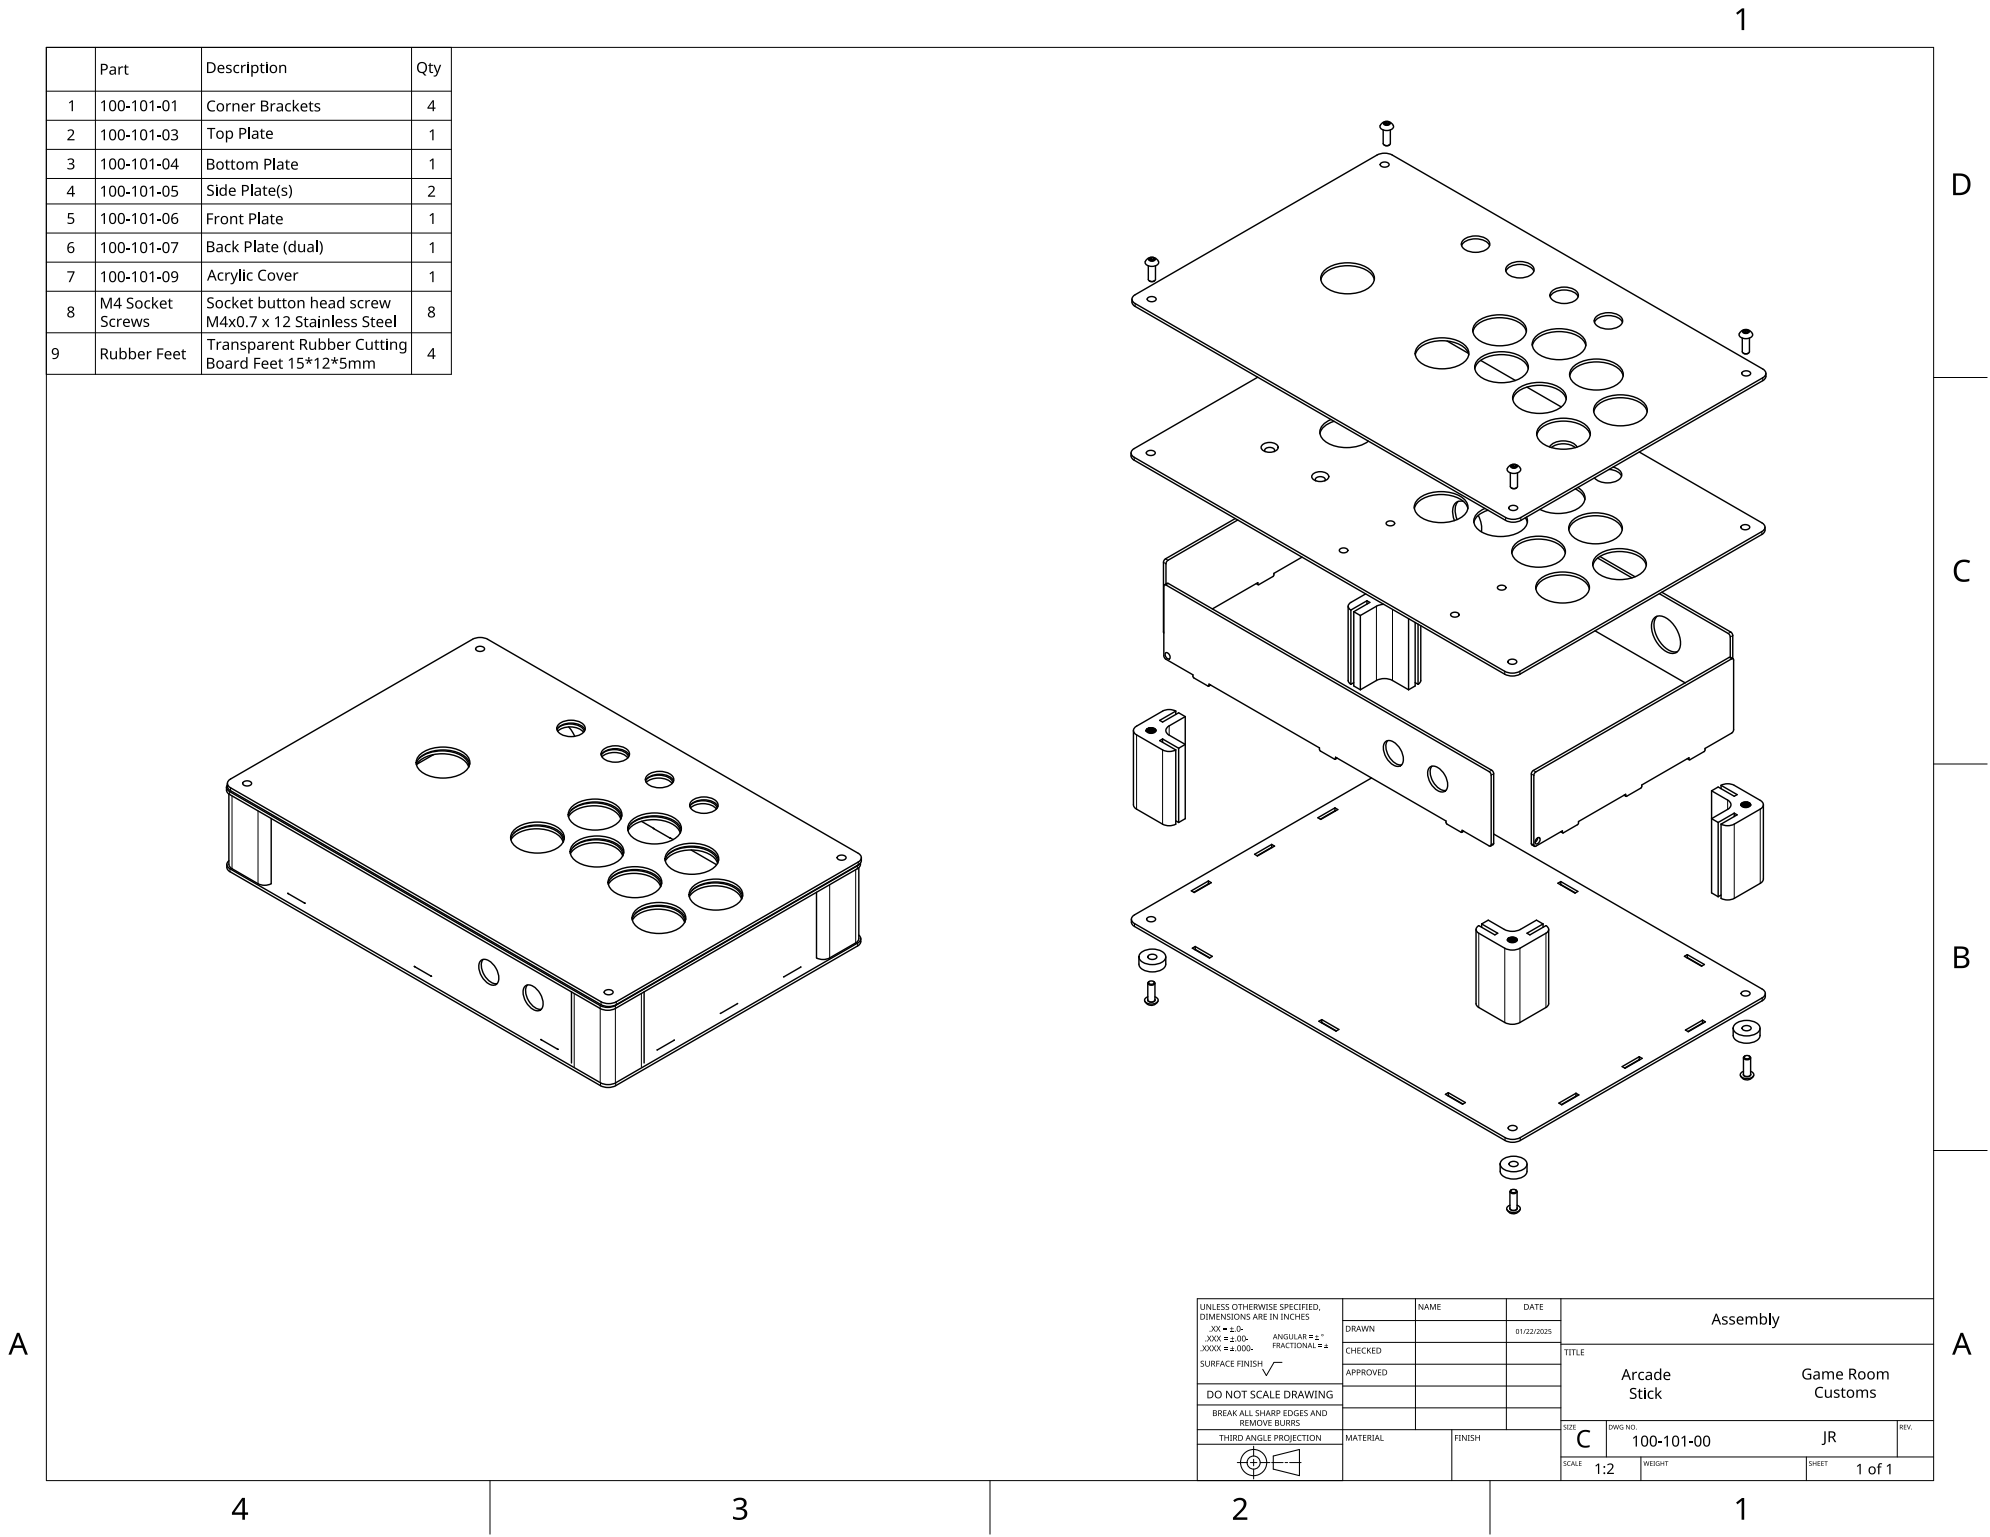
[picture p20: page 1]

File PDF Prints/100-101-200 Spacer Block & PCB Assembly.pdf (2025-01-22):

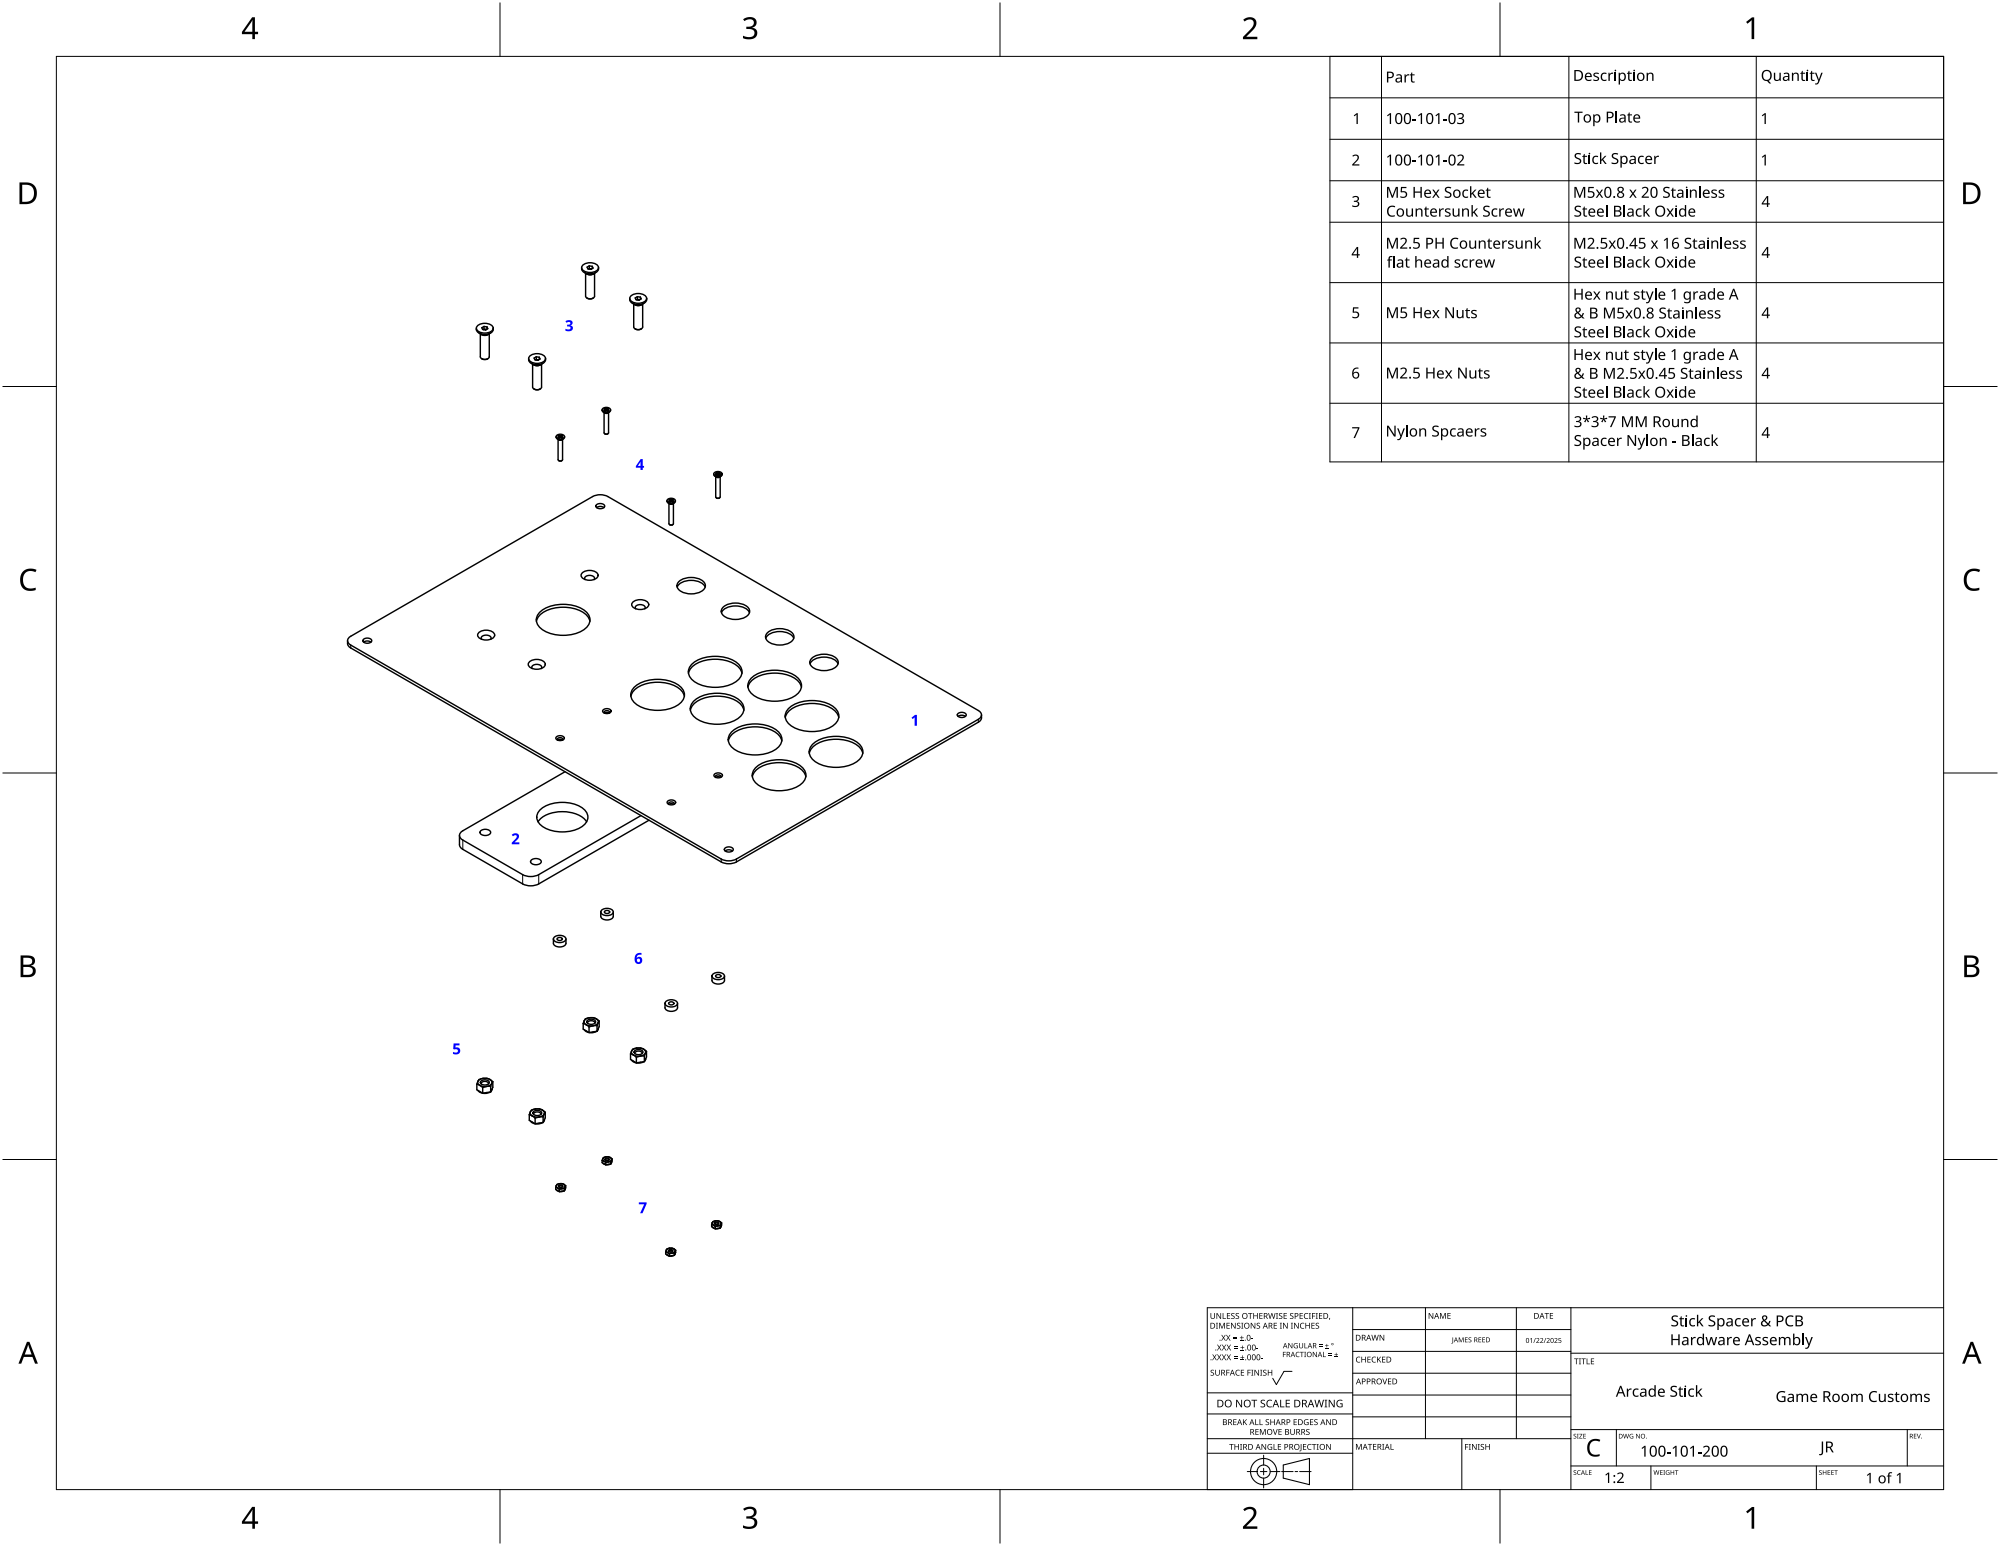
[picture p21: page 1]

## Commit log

2025-01-17 Uploaded 2D CAD Files
    Metal Components and Plastic Cover
    [Acrylic Cover_2mm Clear.dxf, Back Plate Dual Mount_14GA CRS.dxf, Black Plate Single Mount_14GA CRS.dxf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]
2025-01-17 Updated DXF's, Added PDF Print Set, STL Files
    [Bottom Plate_14GA.dxf, Corner Brackets.stl, Stick Spacer.stl]
2025-01-22 Updates
    Updated PDF Drawings, BOM
    [BOM.xlsx]
2025-01-28 Changed Size of Acyrlic
    Changed from 2mm to 1.6mm to work for Genuine Sanwa Buttons
